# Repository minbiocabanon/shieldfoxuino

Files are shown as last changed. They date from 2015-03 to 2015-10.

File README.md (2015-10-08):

Shieldfoxuino
============

GPS tracker on an Olimexino-328 board + my Shield with TD1202 (SIGFOX) and GPS modules

More info about sigfox and Telecom Design modules : 

- http://www.sigfox.com/
- http://rfmodules.td-next.com/

How it works ?
============

SIGFOX is an IoT network provider, it allows devices to send data with long range distance. Payload message is light (12 bytes), but it is very low power and subscription is cheap.
Messages are stored in SIGFOX server that is accessible from any device connected to the Internet.

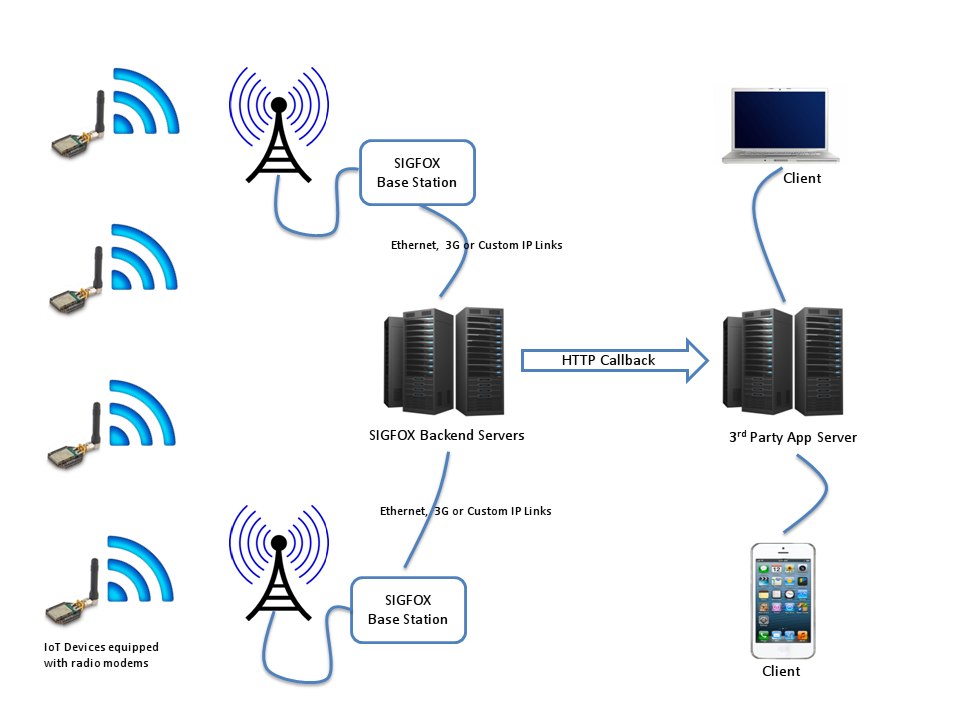
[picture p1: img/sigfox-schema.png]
sigfox archi
 
(source http://www.ekito.fr/)

The shieldfoxuino tracker is composed with a shield plugged in the olimexino-328.

 * Use Sigfow network for communication (uplink only, bidirecionnal mode is NOT supported),
 * Use GPS for geolocalisation and geofencing,
 * Monitor LiPo cell voltage and can set an alarm on low power,
 * Monitor temperature,
 * Serial messages are for debug purpose only.

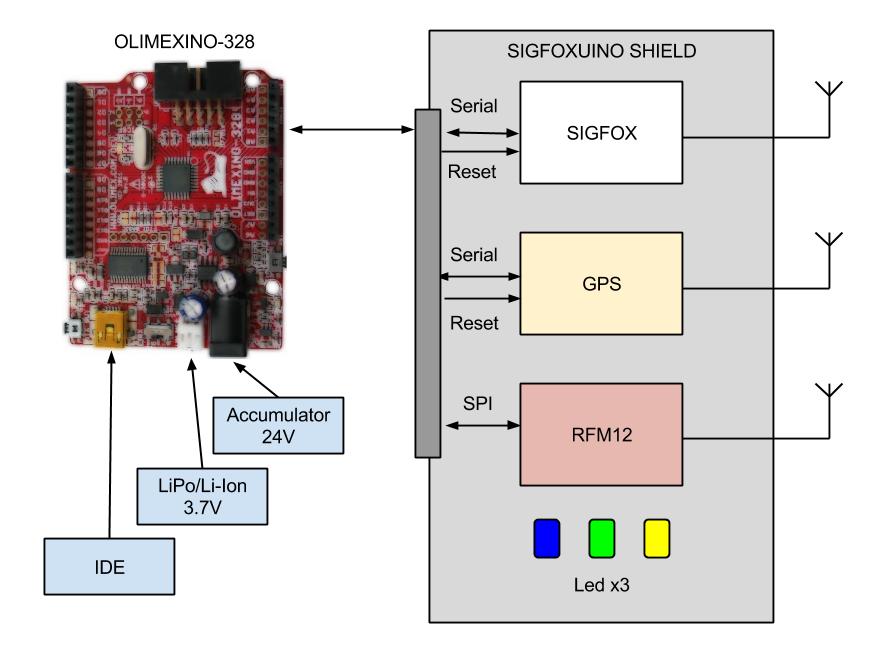
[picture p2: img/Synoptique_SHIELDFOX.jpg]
Shieldfoxuino architecture
 
 
Applications
============ 

 * My application : GPS tracker / Geofencing for my robomow (anti theft)
 * Other application without modifying source code : Geofencing, monitoring for yatch / boat parked at the harbor, ...
 * Other applications which some modification : GPS tracker for car / truck / caravan , freezer monitoring in second home when power outage, ...

Principles
============

##Geofencing

The device check if GPS position is inside an round area centered on an custom coordinates.
When device is outside this area, a message alert is through Sigfox to your server. Server application can warn you by email or SMS.

##Daily report
Each day, shieldfoxuino send a message as a keepalive message.
Message is the same as the geofencing message.

##Analog inputs

The device can monitor some analog inputs :

- LiPo battery : linkitone API only return these levels : 0 - 33 - 66 - 100% . So, by default, an SMS alert is sent to your phone when LiPo voltage is lower than 33%. This trigger is not customizable by SMS.

- Power supply voltage : device read voltage of this input and can send an SMS when is lower than a trigger. This value can be set by SMS. Default value is 11.6V (for a 12V lead battery).

## Serial port

Serial port is available on micro USB connector. It is only for debugging purpose. No maintenance or configuration messages are available through this serial port.

Screenshots
============

#Hardware setup

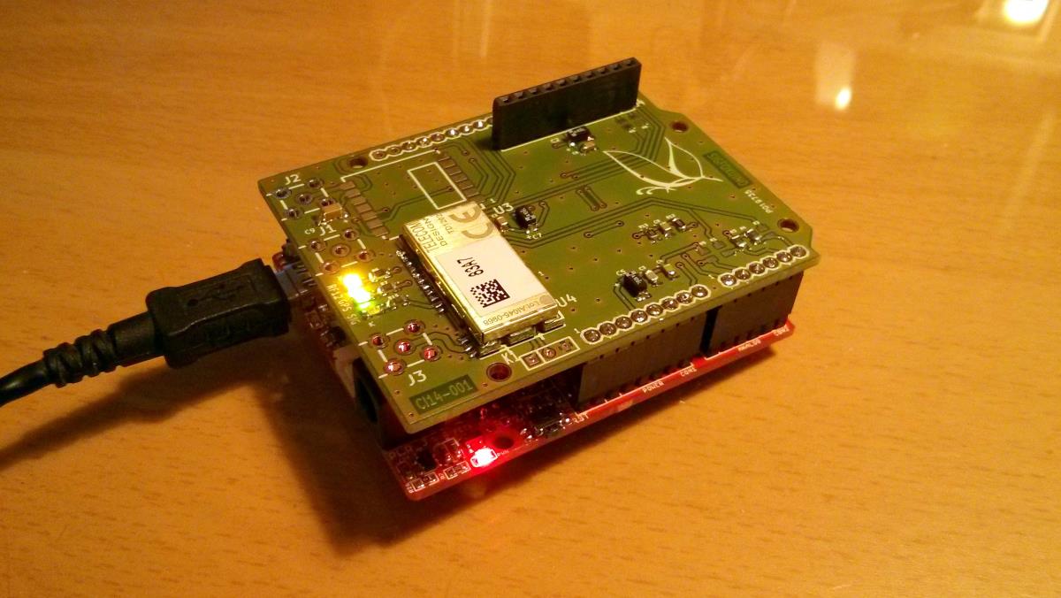
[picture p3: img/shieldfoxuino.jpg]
shieldfoxuino pic


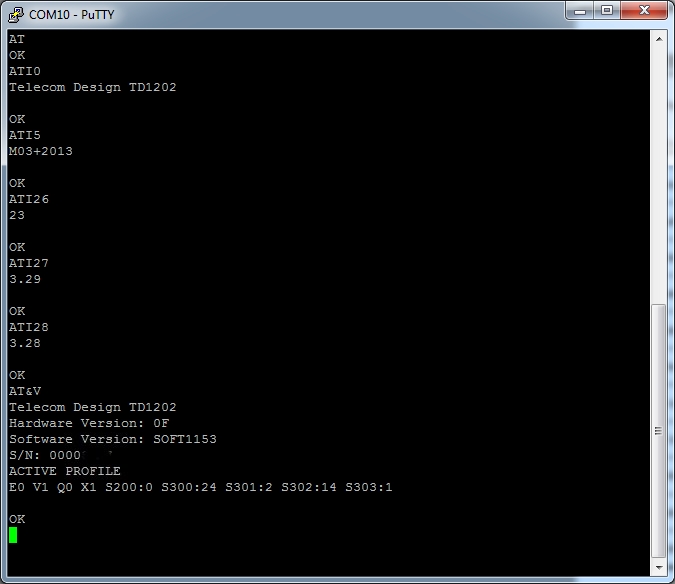
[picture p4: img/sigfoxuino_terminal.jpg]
Terminal pic


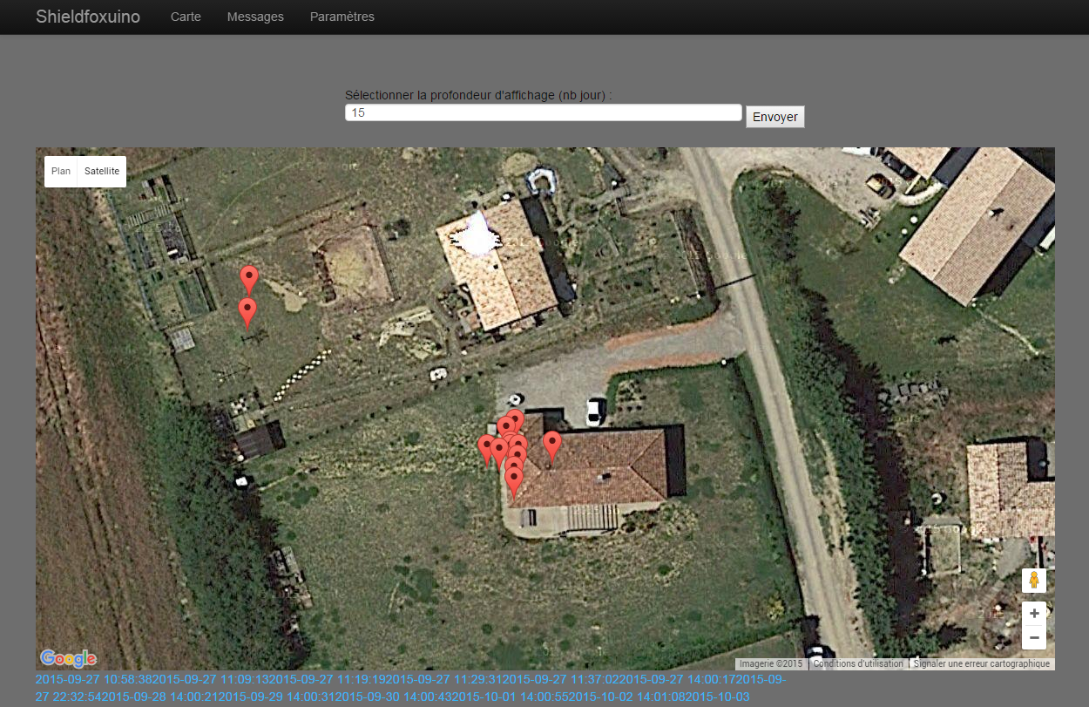
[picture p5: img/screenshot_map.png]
Map pic


Instructions
============

Don't forget to set your settings in this file :

	~\shieldfoxuino\soft\sketche_sigfoxuino\sketche_sigfoxuino.h

Compile files and uploard to olimexino-328 with arduino IDE (follow instructions in Developer's guide)

Software
============
Arduino IDE version must be 1.5.0 ! (newer version are not supported yet).

Sigfox serial interface driver is forked from this hub :
https://github.com/Ekito/hackerz_aker

API IoT 
============
Once message is send to SIGFOX network, the only way to get this message is to run a request from a machine connected to the Internet (server, computer, mobile phone ...)
You have to ask to your Sigfox provider the API side.

  * backend SIGFOX : [[https://backend.sigfox.com]]
  * backend Telecom Design : [[https://developers.insgroup.fr/]]

Hardware
============
- Olimexino-328

https://www.olimex.com/Products/Duino/AVR/OLIMEXINO-328/open-source-hardware

- plastic case

http://www.seeedstudio.com/depot/General-Plastic-Case-25x60x100-mm-p-1001.html

Troubleshooting
============

TODO

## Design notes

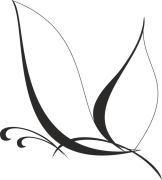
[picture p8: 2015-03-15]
img/vector_butterfly_by_jittike-d32rp64.png

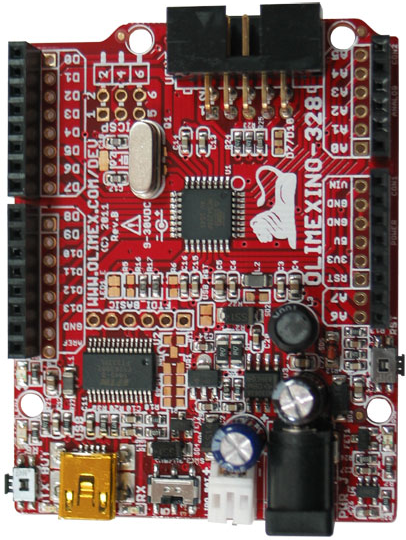
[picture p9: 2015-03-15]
Olimex/olimex328.png

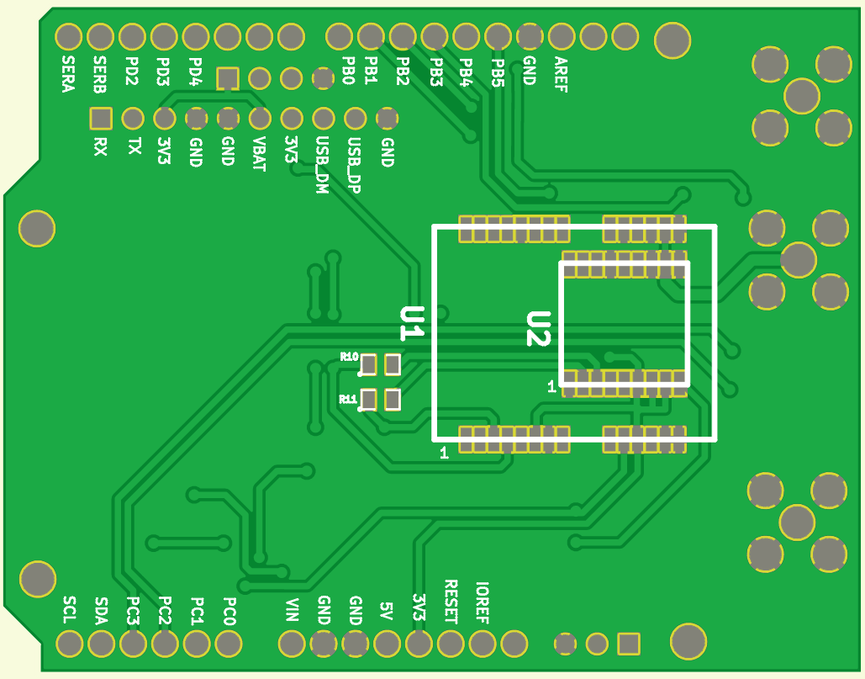
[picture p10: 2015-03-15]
schema/IMPLANTATION/CI14-001_bottom.png

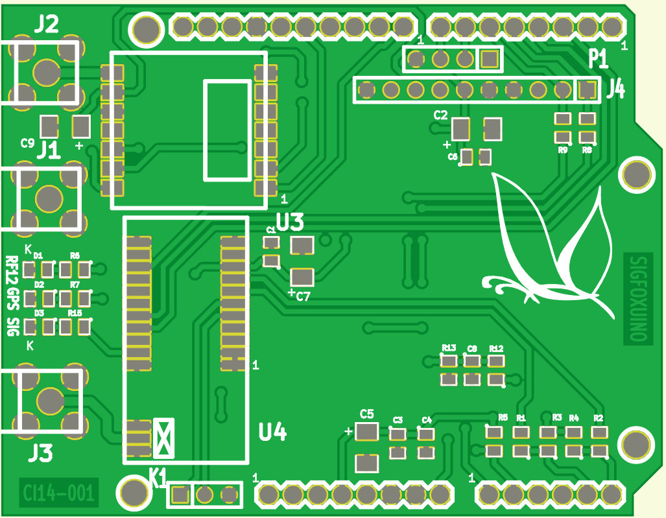
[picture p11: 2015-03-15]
schema/IMPLANTATION/CI14-001_top.png

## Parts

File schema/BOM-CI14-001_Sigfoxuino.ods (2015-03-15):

N° de circuit |  | CI14-001
 |  |  |  |  |  |  |  | Total | 21,91 €
 |  |  |  |  |  | TVA | 1,196
ref | value | footprint | Fabricant | Designation | Fournisseur | code commande |  | Prix U TTC | Prix U TTC
PCB | CI14-001 |  |  | 2 couches , 53,55 x 69,00mm | Eurocircuit | FDP compris | 3,62 € | 4,32 €
C3 | 10pF | SM0805 |  | Condensateur |  |  | 0,00 € | 0,00 €
C5 | 10uF/9V | SM1206 |  | Condensateur |  |  | 0,00 € | 0,00 €
C2 | 10uF/9V | SM1206 |  | Condensateur |  |  | 0,00 € | 0,00 €
C7 | 10uF/9V | SM1206 |  | Condensateur |  |  | 0,00 € | 0,00 €
C6 | 0.1uF | SM0805 |  | Condensateur |  |  | 0,00 € | 0,00 €
C8 | 0.1uF | SM0805 |  | Condensateur |  |  | 0,00 € | 0,00 €
C1 | 0.1uF | SM0805 |  | Condensateur |  |  | 0,00 € | 0,00 €
C4 | 0.1uF | SM0805 |  | Condensateur |  |  | 0,00 € | 0,00 €
CON6_1 | SIL06 | TSW-106-07-L-S | SAMTEC | Barette 6pts male droite | Conrad Farnell | 733993-62 1668590 | 0,15 € | 0,18 € | Gratuit en sample sur Samtec.com
CON8_2 | SIL08 | TSW-108-07-L-S | SAMTEC | Barette 8pts male droite | Conrad Farnell | 742235 – 62 - | 0,20 € | 0,24 € | Gratuit en sample sur Samtec.com
CONN10_1 | SIL10 | TSW-110-07-L-S | SAMTEC | Barette 10pts male droite | Conrad Farnell | 393481 – 62 - | 0,15 € | 0,18 € | Gratuit en sample sur Samtec.com
CONN8_1 | SIL8 | TSW-108-07-L-S | SAMTEC | Barette 8pts male droite | Conrad Farnell | 742235 – 62 - | 0,20 € | 0,24 € | Gratuit en sample sur Samtec.com
D1 | LED GREEN | SM0805 | Avago / Osram | Led CMS verte | Conrad Farnell | 153376–62 2099239 | 0,20 € | 0,24 €
D2 | LED GREEN | SM0805 | Avago / Osram | Led CMS Jaune | Conrad Farnell | 153392 – 62 - | 0,15 € | 0,18 €
D3 | LED GREEN | SM0805 | Avago / Osram | LED CMS bleu | Conrad Farnell | 759433 – 62 - | 0,30 € | 0,36 €
J1 | SMA_TH | SMA-J-P-XX-RA-TH1 | SAMTEC | Embase SMA long filetage femelle coudée 50 Ω CI | Conrad Farnell |  | 3,80 € | 4,54 € | Gratuit en sample sur Samtec.com
J2 | SMA_TH | SMA-J-P-XX-RA-TH1 | BKL | Embase SMA long filetage femelle coudée 50 Ω CI | Conrad Farnell |  | 3,80 € | 4,54 € | Gratuit en sample sur Samtec.com
J3 | SMA_TH | SMA-J-P-XX-RA-TH1 | BKL | Embase SMA long filetage femelle coudée 50 Ω CI | Conrad Farnell |  | 3,80 € | 4,54 € | Gratuit en sample sur Samtec.com
J4 | SIL10 | SSW-110-01-F-S | SAMTEC | Barette 10pts Femelle droite | Conrad Farnell | 741129 – 62 - | 0,65 € | 0,78 € | Gratuit en sample sur Samtec.com
K1 | SIL10 | SSW-110-01-F-S | SAMTEC | Barette 10pts Femelle droite | Conrad Farnell | 741129 – 62 - | 0,65 € | 0,78 € | Gratuit en sample sur Samtec.com
P1 | SIL10 | SSW-110-01-F-S | SAMTEC | Barette 10pts Femelle droite | Conrad Farnell | 741129 – 62 - | 0,65 € | 0,78 € | Gratuit en sample sur Samtec.com
R1 | 0R0 | SM0805 |  | Résistance 10 % |  |  | 0,00 € | 0,00 €
R2 | 0R0 | SM0805 |  | Résistance 10 % |  |  | 0,00 € | 0,00 €
R3 | 4K7 | SM0805 |  | Résistance 10 % |  |  | 0,00 € | 0,00 €
R4 | 4K7 | SM0805 |  | Résistance 10 % |  |  | 0,00 € | 0,00 €
R5 | 47K | SM0805 |  | Résistance 10 % |  |  | 0,00 € | 0,00 €
R6 | 220R | SM0805 |  | Résistance 10 % |  |  | 0,00 € | 0,00 €
R7 | 220R | SM0805 |  | Résistance 10 % |  |  | 0,00 € | 0,00 €
R8 | 0R | SM0805 |  | Résistance 10 % |  |  | 0,00 € | 0,00 €
R9 | 0R | SM0805 |  | Résistance 10 % |  |  | 0,00 € | 0,00 €
R10 | 0R | SM0805 |  | Résistance 10 % |  |  | 0,00 € | 0,00 €
R11 | 0R | SM0805 |  | Résistance 10 % |  |  | 0,00 € | 0,00 €
R12 | 10K | SM0805 |  | Résistance 10 % |  |  | 0,00 € | 0,00 €
R13 | 1K | SM0805 |  | Résistance 10 % |  |  | 0,00 € | 0,00 €
R15 | 220R | SM0805 |  | Résistance 10 % |  |  | 0,00 € | 0,00 €
U1 | LEA-7X | LEA-xx | uBlox | Récepteur GPS |  |  | 0,00 € | 0,00 €
U2 | MAX-7X | MAX-xx | uBlox | Récepteur GPS |  |  | 0,00 € | 0,00 €
U3 | RFM12 | RFM12 | HopeRF | E/R radio 869MHz/433Mhz |  |  | 0,00 € | 0,00 €
U4 | TD1202 | TD1202 | Telecom Design | E/R radio 869MHz longue portée |  |  | 0,00 € | 0,00 €
ACCESSOIRES
ref | value | footprint | Fabricant | Designation | Fournisseur | code commande |  | Prix U TTC
 | OLIMEXINO-328 |  | OLIMEX | Cartes compatible arduino UNO | LEXTRONIC | OLIMEX328 | 24,75 € | 29,60 €
 | LEA Smart antenna |  | Ublox | Kit récepteur GPS + antenne céramique

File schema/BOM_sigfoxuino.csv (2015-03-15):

ref | value | footprint
C1 | 0.1uF | SM0805
C2 | 10uF/9V | SM1206
C3 | 10pF | SM0805
C4 | 0.1uF | SM0805
C5 | 10uF/9V | SM1206
C6 | 0.1uF | SM0805
C7 | 10uF/9V | SM1206
C8 | 0.1uF | SM0805
C9 | 1uF/9V | SM1206
CON6_1 | CONN_6 | SIL-6
CON8_2 | CONN_8 | SIL-8
CONN10_1 | CONN_10 | SIL-10
CONN8_1 | CONN_8 | SIL-8
D1 | LED GREEN | SM0805
D2 | LED GREEN | SM0805
D3 | LED GREEN | SM0805
J1 | SMA_TH | SMA-SMB_right_angle
J2 | SMA_TH | SMA-SMB_right_angle
J3 | SMA_TH | SMA-SMB_right_angle
J4 | SIL10 | SIL-10
K1 | CONN_3 | SIL-3
P1 | CONN_4 | ~
R1 | 0R0 | SM0805
R2 | 0R0 | SM0805
R3 | 4K7 | SM0805
R4 | 4K7 | SM0805
R5 | 47K | SM0805
R6 | 220R | SM0805
R7 | 220R | SM0805
R8 | 0R | SM0805
R9 | 0R | SM0805
R10 | 0R | SM0805
R11 | 0R | SM0805
R12 | 10K | SM0805
R13 | 1K | SM0805
R15 | 220R | SM0805
U1 | LEA-7X | LEA-xx
U2 | MAX-7X | MAX-xx
U3 | RFM12 | RFM12
U4 | TD1202 | TD1202

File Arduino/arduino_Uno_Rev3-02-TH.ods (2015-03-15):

Arduino Uno R3 Through-Hole |  |  |  | Rugged Circuits LLC http://ruggedcircuits.com Look for the latest version at http://ruggedcircuits.com/html/application_notes.html This bill-of-materials is a best-effort estimate and comes with no warranty. Please direct all corrections to <support@ruggedcircuits.com>
 | Qty | Part Number | Manufacturer | Package | Reference | Description | Digi-Key P/N | Mouser P/N | Newark P/N
Capacitors
 | 2 | 500R14N220JV4T | Johanson | 0603 | C9, C11 | 22pF capacitor ceramic | 709-1143-1-ND
 | 2 | MC0603N220J500CT | Multicomp | 0603 | C9, C11 | 22pF capacitor ceramic |  |  | 06R5149
 | 2 | VJ0603A220KXQPW1BC | Vishay | 0603 | C9, C11 | 22pF capacitor ceramic |  | 77-VJ0603A220KXQPBC
 | 6 | CC0603KRX7R9BB104 | Yageo | 0603 | C1, C2, C4, C5, C6, C7 | 100nF capacitor ceramic | 311-1344-1-ND
 | 6 | C0603C104K5RACTU | Kemet | 0603 | C1, C2, C4, C5, C6, C7 | 100nF capacitor ceramic |  |  | 72J5992
 | 6 | GRM188R71H104KA93D | Murata | 0603 | C1, C2, C4, C5, C6, C7 | 100nF capacitor ceramic | 490-1519-1-ND | 81-GRM39X104K50D | 38K1670
 | 2 | GRM188R60J105KA01D | Murata | 0603 | C3, C8 | 1uF capacitor ceramic 6.3V | 490-1550-1-ND | 81-GRM39R105K6.3
 | 2 | C1608X5R1A105MT | TDK | 0603 | C3, C8 | 1uF capacitor ceramic 10V |  | 810-C1608X5R1A105M
 | 2 | EMVA250ADA470MF55G | UCC | SMD | PC1, PC2 | 47uF electrolytic capacitor SMT | 565-2103-1-ND | 661-EMVA250ADA470MF5 | 76K1185
 | 2 | AVE476M50X16T-F | Cornell | SMD | PC1, PC2 | 47uF electrolytic capacitor SMT |  | 598-AVE476M50X16T-F
Connectors
 | 1 | PJ-102A | CUI | PTH | X1 | 2.1mm DC power jack | CP-102A-ND
 | 1 | USB-B1HSW6 | On Shore | PTH | X2 | USB type B connector right-angle – white | ED2982-ND
 | 1 | USB-B1HSB6 | On Shore | PTH | X2 | USB type B connector right-angle – black | ED2983-ND
 | 1 | 67996-404HLF | FCI | PTH | JP2 | Pin header 0.1” 2x2 | 609-3390-ND | 649-67996-404HLF
 | 2 | 67996-406HLF | FCI | PTH | ICSP, ICSP1 | Pin header 0.1” 2x3 | 609-3218-ND | 649-67996-406HLF | 20M2191
 | 1 | M20-7820646 | Harwin | PTH | AD | Socket strip 0.1” 1x6 |  | 855-M20-7820646
 | 1 | 5-534237-4 | TE | PTH | AD | Socket strip 0.1” 1x6 | A32907-ND |  | 62M8851
 | 2 | 960108-6202-AR | 3M | PTH | IOL, POWER | Socket strip 0.1” 1x8 | 3M9518-ND | 517-9601086202AR | 62R6734
 | 2 | M20-7820842 | Harwin | PTH | IOL, POWER | Socket strip 0.1” 1x8 |  | 855-M20-7820842
 | 1 | M20-7821046 | Harwin | PTH | IOH | Socket strip 0.1” 1x10 |  | 855-M20-7821046
 | 1 | 5-534237-8 | TE | PTH | IOH | Socket strip 0.1” 1x10 | A32910-ND | 571-5-534237-8 | 52K3746
Crystals
 | 1 | ATS16B | CTS | HC49/US | Y1 | 16MHz 18pF | CTX1085-ND | 774-ATS16B
 | 1 | ABL-16.000MHZ-B2 | Abracon | HC49/US | Y1 | 16MHz 18pF |  | 815-ABL-16-B2 | 13J1628
Diodes
 | 2 | CD1206-S01575 | Bourns | 1206 | D2, D3 | Switching diode |  | 652-CD1206-S01575 | 09J8040
 | 1 | S2M-13-F | Diodes Inc | SMB | D1 | Switching diode | S2M-FDICT-ND | 621-S2M-F
 | 1 | S2J | Fairchild | SMB | D1 | Switching diode | S2J-TPMSCT-ND | 512-S2J | 05R5915
Ferrites
 | 1 | BLM21PG221SN1D | Murata | 0805 | L1 | Ferrite 50mOhm@DC / 220ohm@100MHz | 490-1054-1-ND | 81-BLM21P221SG
Fuses
 | 1 | MF-MSMF050-2 | Bourns | 1812 | F1 | Fuse 500mA 15V | MF-MSMF050-2CT-ND | 652-MF-MSMF050-2 | 02J2718
IC's
 | 1 | ATMEGA16U2-MUR | Atmel | VQFN-32 | U3 | ATmega16U2 16kB FLASH | ATMEGA16U2-MURCT-ND | 556-ATMEGA16U2-MUR
 | 1 | ATMEGA328P-PU | Atmel | DIP-28 | ZU4 | ATmega328P | ATMEGA328P-PU-ND | 556-ATMEGA328P-PU | 15R0268
 | 1 | LMV358IDGKR | TI | MSOP-8 | U5 | Dual op-amp RRO | 296-13455-1-ND | 595-LMV358IDGKR
 | 1 | MCP6002-E/MS | Microchip | MSOP-8 | U5 | Dual op-amp RRO | MCP6002-E/MS-ND | 579-MCP6002-E/MS | 88H9854
 | 1 | LP2985-33DBVR | TI | SOT-23-5 | U2 | 150mA 3.3V LDO | 296-18476-1-ND | 595-LP2985-33DBVR | 43J9346
 | 1 | NCP1117ST50T3G | ON Semi | SOT-223 | U1 | 1A 5V LDO | NCP1117ST50T3GOSCT-ND | 863-NCP1117ST50T3G | 71J6563
LED's
 | 1 | LG R971-KN-1-0-20-R18 | Osram | 0805 | ON | LED green | 475-1410-1-ND
 | 1 | 598-8160-107F | Dialight | 0805 | ON | LED green | 350-2043-1-ND | 645-598-8160-107F | 75R0586
 | 3 | LTST-C171KSKT | Lite-On | 0805 | L, RX, TX | LED yellow | 160-1428-1-ND | 859-LTST-C171KSKT
 | 3 | APT2012YC | Kingbright | 0805 | L, RX, TX | LED yellow | 754-1135-1-ND | 604-APT2012YC
Resistors
 | 1 | CAY16-220J4LF | Bourns | 1206 | RN3 | 22ohm 4-resistor series array | CAY16-220J4LF-ND | 652-CAY16-220J4LF
 | 2 | CAY16-102J4LF | Bourns | 1206 | RN2, RN4 | 1k 4-resistor series array | CAY16-102J4LF-ND | 652-CAY16-102J4LF | 96M0890
 | 1 | CAY16-103J4LF | Bourns | 1206 | RN1 | 10k 4-resistor series array | CAY16-103J4LF-ND | 652-CAY16-103J4LF | 02J1097
 | 2 | ERJ-3GEYJ105V | Panasonic | 0603 | R1, R2 | 1M resistor 5% 1/10W | P1.0MGCT-ND | 667-ERJ-3GEYJ105V
 | 2 | CR0603-JW-105GLF | Bourns | 0603 | R1, R2 | 1M resistor 5% 1/10W |  | 652-CR0603-JW-105GLF | 32K2615
Resonators
 | 1 | CSTCE16M0V53-R0 | Murata | SMD | Y2 | 16MHz resonator with built-in caps | 490-1198-1-ND | 81-CSTCE16M0V53-R0
Switches
 | 1 | TS42031-160R-TR-7260 | ??? | SMT | RESET | Tactile switch
Transistors
 | 1 | FDN340P | Fairchild | SOT-23 | T1 | 20V P-type MOSFET | FDN340PCT-ND | 512-FDN340P | 58K8841
Varistors
 | 2 | CG0603MLC-05E | Bourns | 0603 | Z1, Z2 | Low-capacitance varistor 5V WV | CG0603MLC-05E-ND | 652-CG0603MLC-05E | 97M3815

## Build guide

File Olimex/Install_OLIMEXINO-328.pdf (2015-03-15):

## Install OLIMEXINO-328

by LadyMM

The olimexino-328 is an arduino-like borad, which runs programs called “sketches”. The programs themselves are written in C/C++ and compiled in the Arduino environment and then uploaded to the board’s memory via miniUSB.

Special drivers and settings are needed, however, for your computer to correctly recognise the board. Installation instructions are below.

1.Installation of the arduino-based board
(Instrusctions and screenshots from Limor Fried http://www.ladyada.net/learn/arduino)

Visit http://www.ftdichip.com/Drivers/VCP.htm for the latest drivers for your Olimexino-328 board
(Instructions for other arduino boards can be found at http://arduino.cc/en/Guide/HomePage )

Windows:
(The screenshots show a Windows XP machine, but the installation is the same for XP/Vista/Windows7)

When you plug in the Arduino, you may hear a sound from the computer and a little popup bubble in the bottom right corner of the screen that says Found New Hardware FT232R USB UART

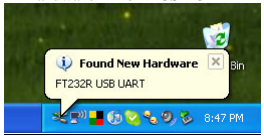
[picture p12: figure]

After a few seconds, the new hardware wizard will start. Select "No not this time" and click Next>

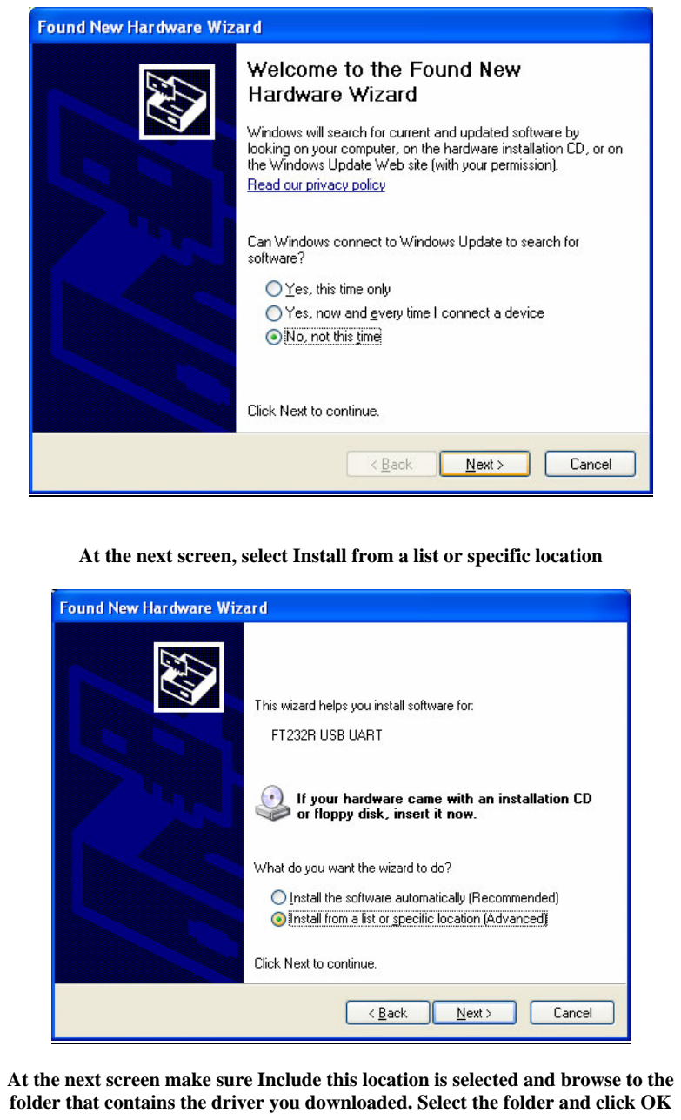
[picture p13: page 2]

At the next screen, select Install from a list or specific location

At the next screen make sure Include this location is selected and browse to the folder that contains the driver you downloaded. Select the folder and click OK

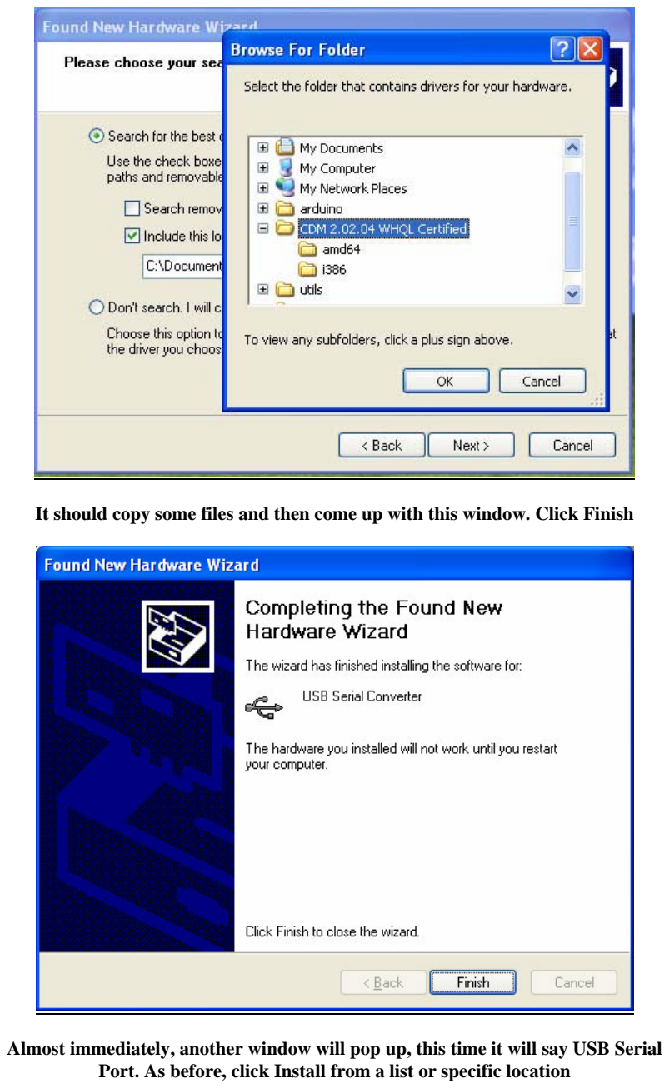
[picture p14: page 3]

It should copy some files and then come up with this window. Click Finish

Almost immediately, another window will pop up, this time it will say USB Serial Port. As before, click Install from a list or specific location

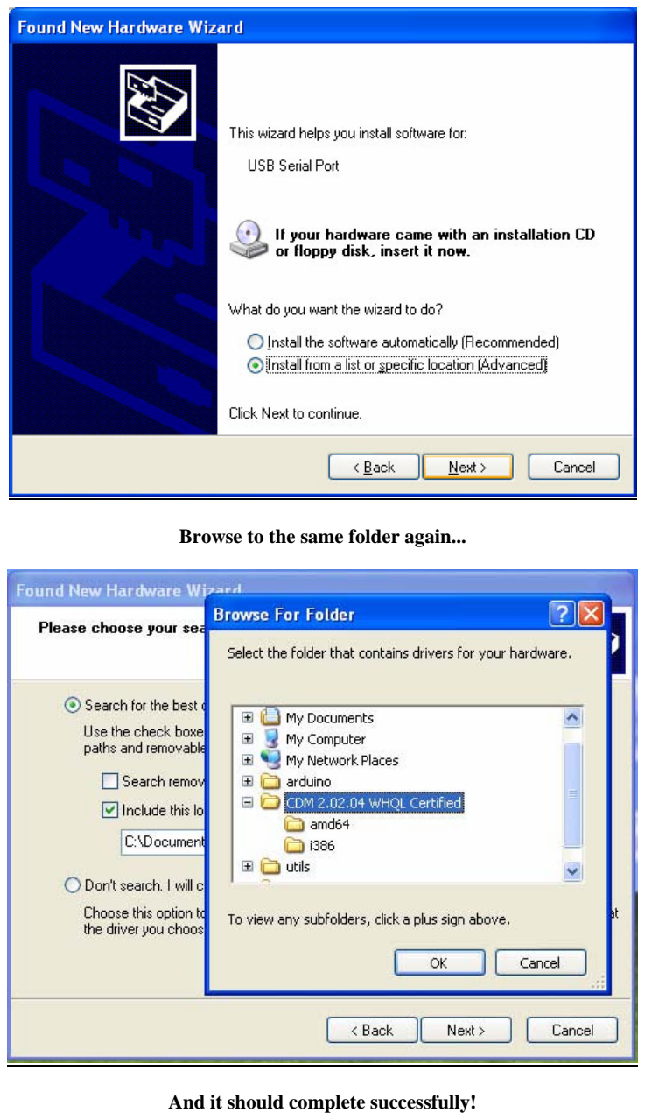
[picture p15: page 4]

Browse to the same folder again...

And it should complete successfully!

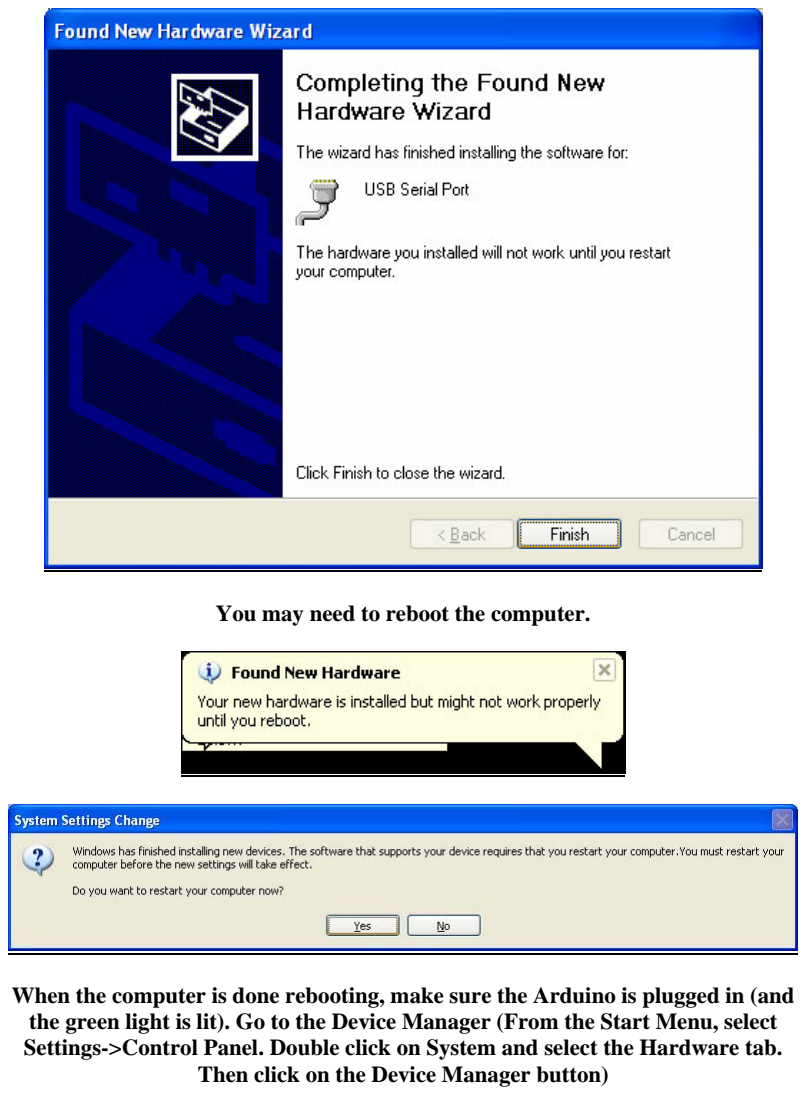
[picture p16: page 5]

You may need to reboot the computer.

When the computer is done rebooting, make sure the Arduino is plugged in (and the green light is lit). Go to the Device Manager (From the Start Menu, select Settings->Control Panel. Double click on System and select the Hardware tab. Then click on the Device Manager button)

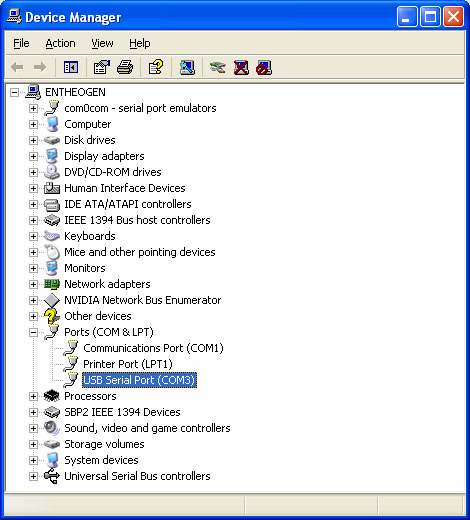
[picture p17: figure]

Look for an entry under Ports (COM & LPT) that says USB Serial Port (COM) the COM number may vary but it should be something like COM3 or COM4. The COM stands for "communication", and each one has a unique number, known as the COM Port number. In this case the COM Port number is COM3.

If you don't see the COM port verify the Arduino is plugged in, and check that you installed the VCP FTDI driver.

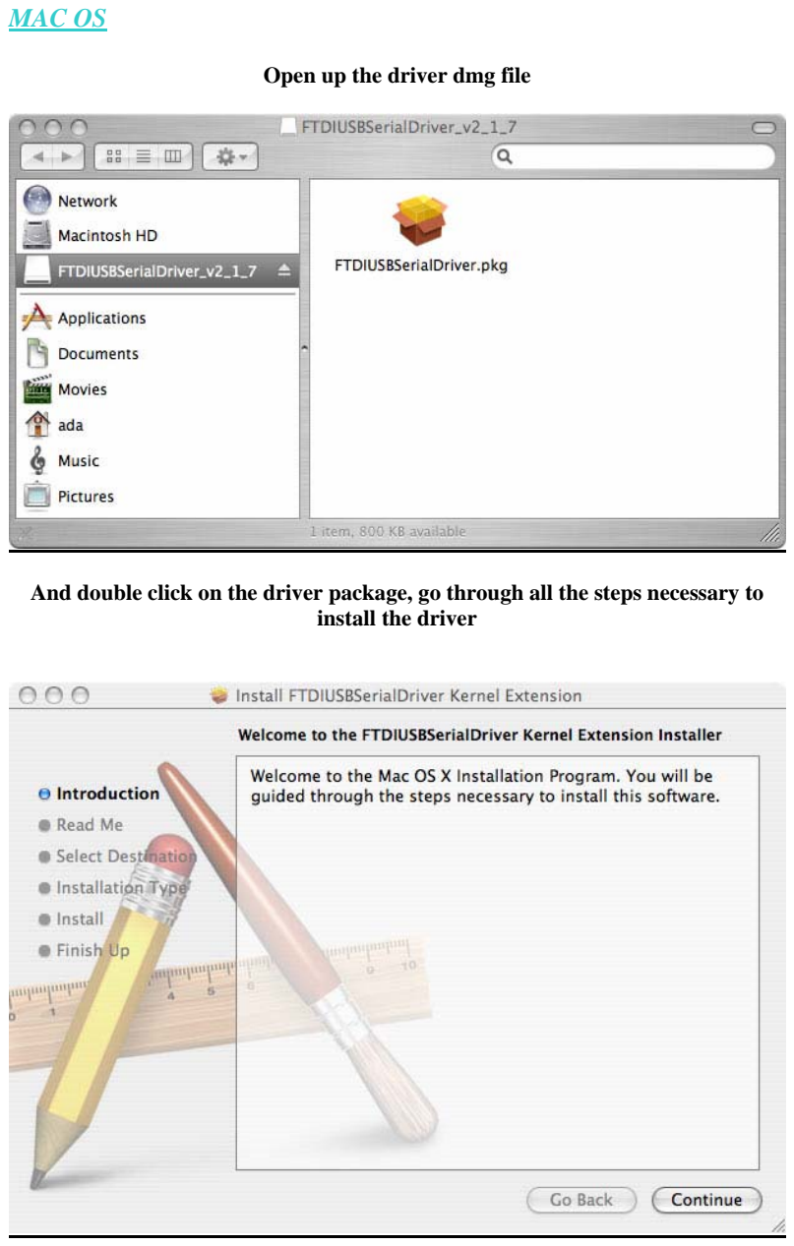
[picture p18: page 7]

MAC OS

Open up the driver dmg file

And double click on the driver package, go through all the steps necessary to install the driver

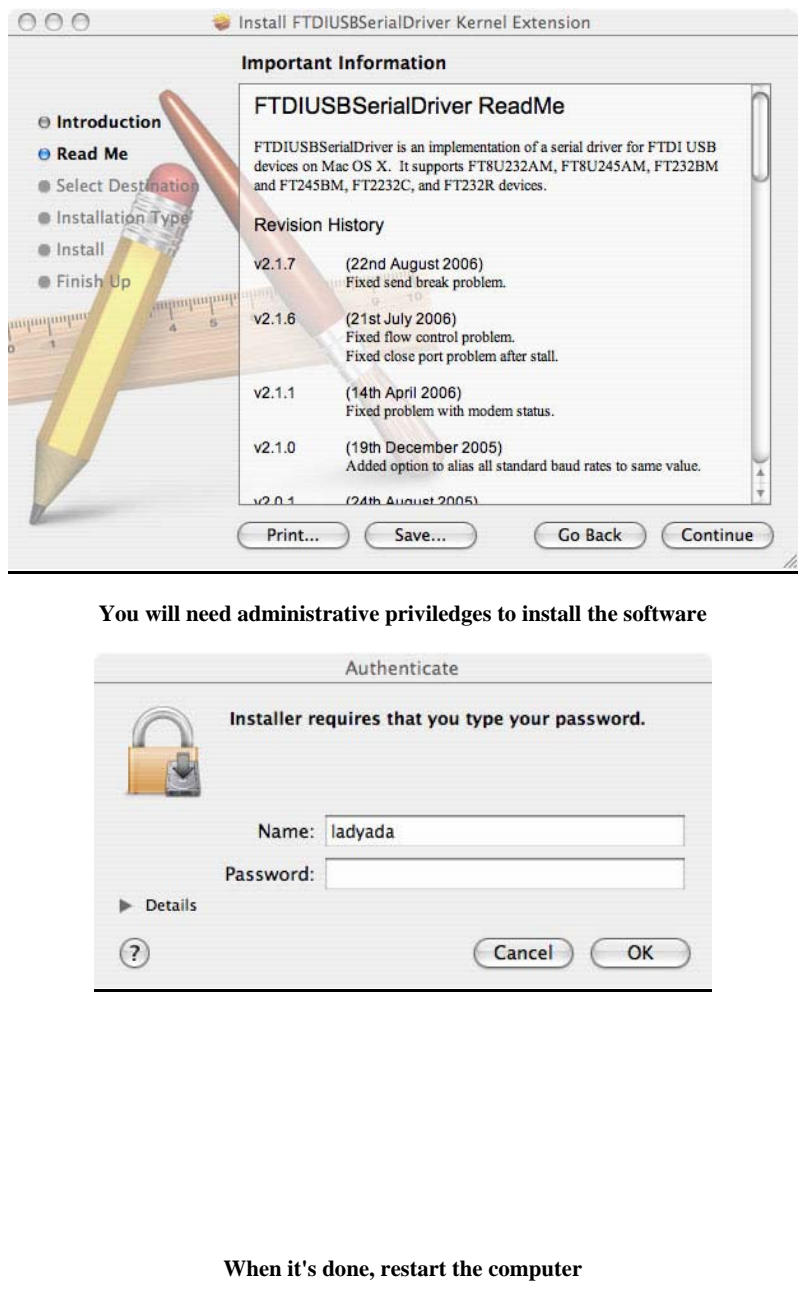
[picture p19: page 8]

You will need administrative priviledges to install the software

When it's done, restart the computer

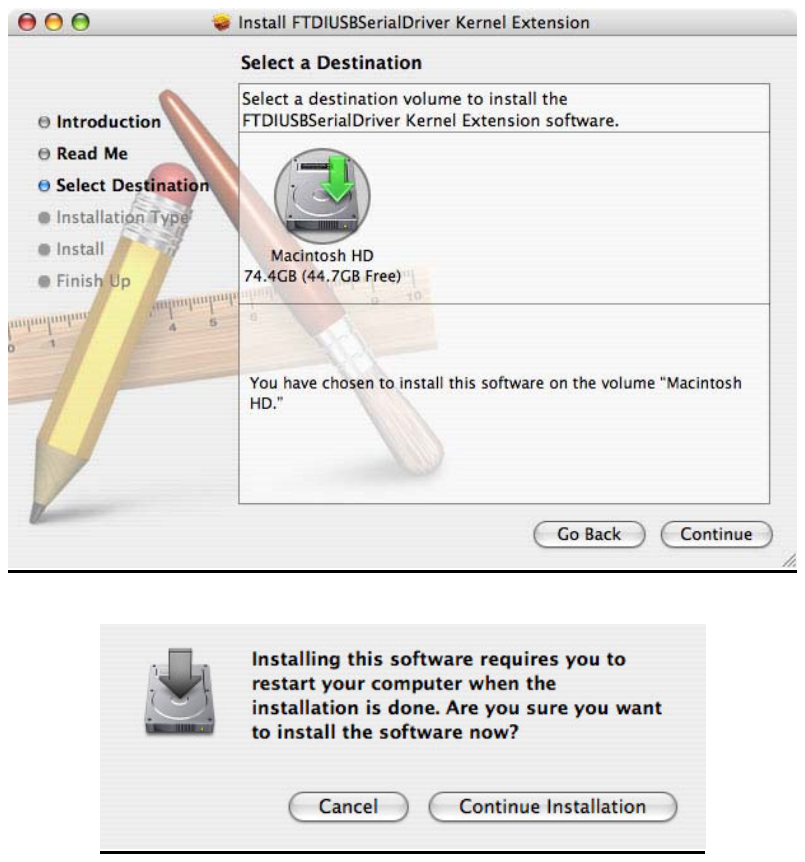
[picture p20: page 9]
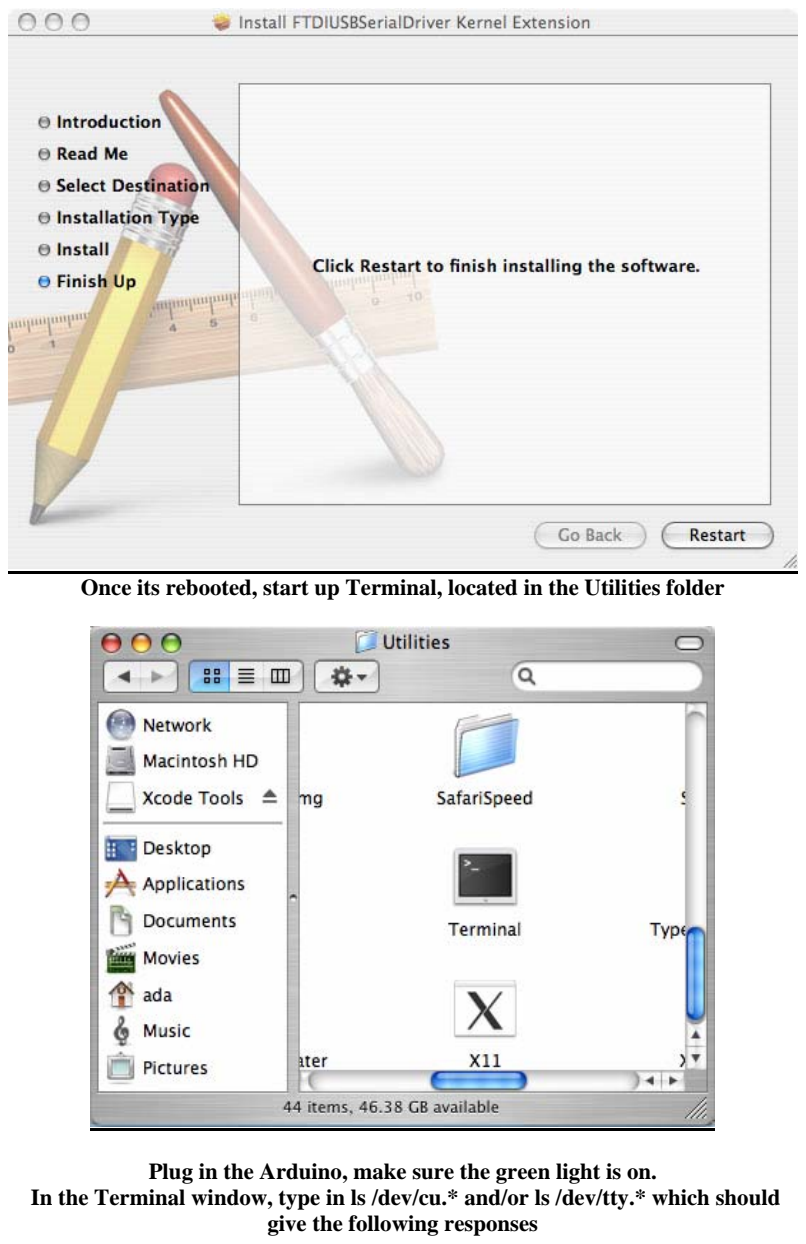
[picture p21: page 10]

Once its rebooted, start up Terminal, located in the Utilities folder

Plug in the Arduino, make sure the green light is on. In the Terminal window, type in ls /dev/cu.* and/or ls /dev/tty.* which should give the following responses

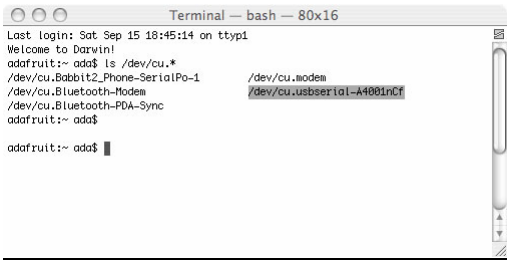
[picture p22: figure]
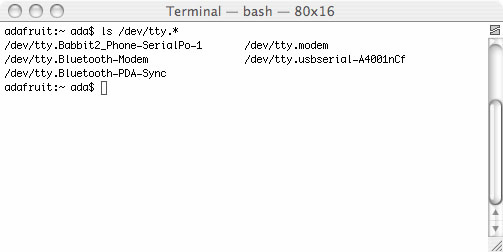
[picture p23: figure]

Make sure you see a line with the text /dev/cu.usbserial-xxxxx where the xxx's can be anything. Same for /dev/tty.usbserial-xxxxx. This indicates that the driver installed properly and that the Arduino was found.

If you can't find the text, verify that your Arduino is plugged in, try a different USB port.
You can also try running the Console application, which will possibly give you some information about why its failing.

### LINUX

Linux doesn't have any drivers to install, assuming you're running a v2.6 kernel. These instructions assume you're running Ubuntu. Each linux distribution is different, but the instructions should be basic enough to follow for other distros.

You can verify your kernel version by running uname -a in a terminal window, note that this kernel is version 2.6.20

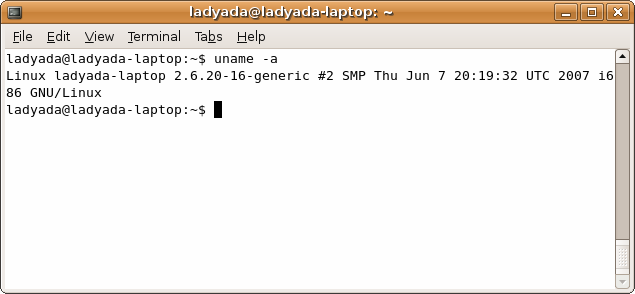
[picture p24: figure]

Sometimes the Linux distribution installs brltty (braille device) which will conflict with the Arduino. You must uninstall brltty! Do so by running

sudo apt-get remove brltty

In a terminal window. If it says it's not installed then thats OK. If you're not running a Debian-derived installation use whatever tool is necessary to verify that you don't have brltty running

Plug in the Arduino, verify that the green LED is lit, and type ls /dev/ttyUSB* into a terminal window, you should see a device file called something like ttyUSB0

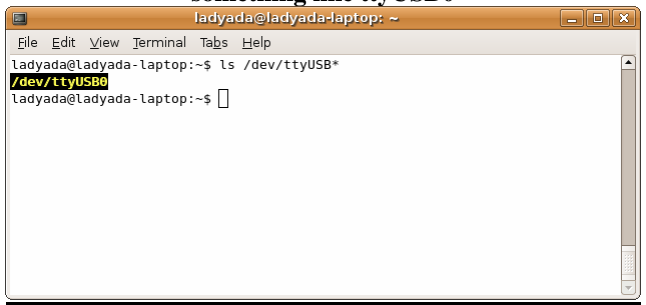
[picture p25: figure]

Depending on your Linux distro, it may be /dev/tty/USB0 or /dev/tty.USB etc.

If you can't seem to find it, use dmesg | tail right after plugging in the
Arduino and look for hints on where it may put the device file. For example here is says Serial Device converter now attached to ttyUSB0

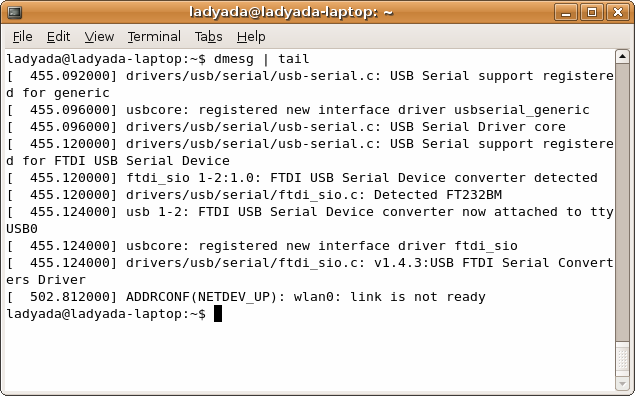
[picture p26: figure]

If you see something like this [ 1900.712000] ftdi_sio 2-10:1.0: FTDI USB Serial Device converter detected
[ 1900.712000] drivers/usb/serial/ftdi_sio.c: Detected FT232BM
[ 1900.712000] usb 2-10: FTDI USB Serial Device converter now attached to ttyUSB0
[ 1901.868000] usb 2-10: usbfs: interface 0 claimed by ftdi_sio while 'brltty' sets config #1
[ 1901.872000] ftdi_sio ttyUSB0: FTDI USB Serial Device converter now disconnected from ttyUSB0
[ 1901.872000] ftdi_sio 2-10:1.0: device disconnected

That means you have not uninstalled brltty and you should try again.

### 2.Configuring The Arduino Environment

### 1. Getting the arduino environment:

Download the latest arduino for your OS from: http://arduino.cc/en/Main/Software

The arduino environment is portable and only needs to be extracted from the archive.

2.Configuring the arduino environment

- Remember the COM port that your board received during installation – then choose the same number from Tools/Serial Port/COMX where X is the number of the correct port.
- Since you are using the Olimexino-328, go to Tools/Board and choose the option shown below on the screenshot.

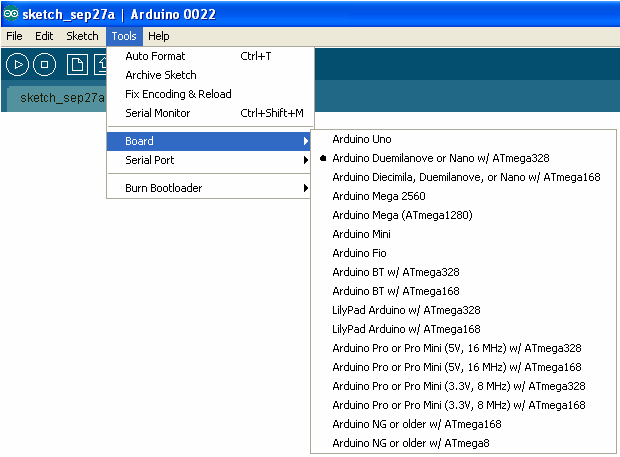
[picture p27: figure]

Now your board should be configured and you can try running some of the example sketches, or start making your own.

Some useful links for those, who are new to the C/C++ language and/or the Arduino environment:

http://arduino.cc/en/Tutorial/HomePagehttp://arduino.cc/en/Reference/HomePagehttp://www.acm.uiuc.edu/webmonkeys/book/c_guide/http://en.wikipedia.org/wiki/C_(programm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 http://arduino.cc/en/Guide

http://www.olimex.com/

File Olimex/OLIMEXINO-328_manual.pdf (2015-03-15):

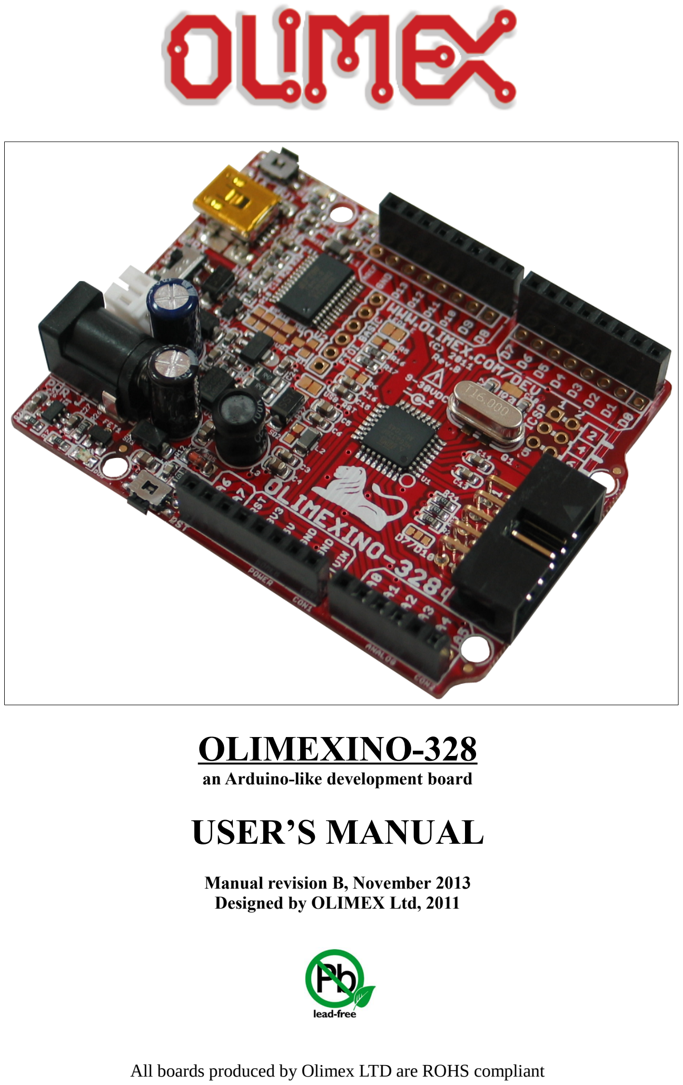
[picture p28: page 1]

# OLIMEXINO-328

an Arduino-like development board

# USER’S MANUAL

Manual revision B, November 2013 Designed by OLIMEX Ltd, 2011

All boards produced by Olimex LTD are ROHS compliant

OLIMEX© 2013 | OLIMEXINO-328 user's manual

### DISCLAIMER

© 2013 Olimex Ltd. Olimex®, logo and combinations thereof, are registered trademarks of Olimex Ltd. Other product names may be trademarks of others and the rights belong to their respective owners.

The information in this document is provided in connection with Olimex products. No license, express or implied or otherwise, to any intellectual property right is granted by this document or in connection with the sale of Olimex products.

This work is licensed under the Creative Commons Attribution-ShareAlike 3.0 Unported License. To view a copy of this license, visit http://www.creativecommons.org/licenses/by-sa/3.0/.

This hardware design by Olimex LTD is licensed under a Creative Commons Attribution-ShareAlike 3.0 Unported License.

The software is released under GPL.

It is possible that the pictures in this manual differ from the latest revision of the board.

The product described in this document is subject to continuous development and improvements. All particulars of the product and its use contained in this document are given by OLIMEX in good faith. However all warranties implied or expressed including but not limited to implied warranties of merchantability or fitness for purpose are excluded. This document is intended only to assist the reader in the use of the product. OLIMEX Ltd. shall not be liable for any loss or damage arising from the use of any information in this document or any error or omission in such information or any incorrect use of the product.

This evaluation board/kit is intended for use for engineering development, demonstration, or evaluation purposes only and is not considered by OLIMEX to be a finished end-product fit for general consumer use. Persons handling the product must have electronics training and observe good engineering practice standards. As such, the goods being provided are not intended to be complete in terms of required design-, marketing-, and/or manufacturing-related protective considerations, including product safety and environmental measures typically found in end products that incorporate such semiconductor components or circuit boards.

Olimex currently deals with a variety of customers for products, and therefore our arrangement with the user is not exclusive. Olimex assumes no liability for applications assistance, customer product design, software performance, or infringement of patents or services described herein.

THERE IS NO WARRANTY FOR THE DESIGN MATERIALS AND THE COMPONENTS USED TO CREATE OLIMEXINO-328. THEY ARE CONSIDERED SUITABLE ONLY FOR OLIMEXINO-328.

## Table of Contents

### CHAPTER 1 - OVERVIEW

### 1. Introduction to the chapter

Thank you for choosing the OLIMEXINO-328 board from Olimex! This document provides a user’s guide for the Olimex Arudino-like OLIMEXINO-328. As an overview, this chapter gives the introduction to Arduino, the scope of this document and lists the features of the board. The document’s organization is then detailed.

### 1.1 Introduction to Arduino

Arduino is an open-source electronics prototyping platform, designed to make the process of using electronics in multidisciplinary projects more accessible. The hardware consists of a simple open design for the Arduino board with an Atmel AVR processor and on-board I/O support. The software consists of a standard programming language and the boot loader that runs on the board.
Arduino hardware is programmed using a Wiring-based language (syntax + libraries), similar to C+ + with some simplifications and modifications, and a processing-based IDE.

The project began in Ivrea, Italy in 2005 to make a device for controlling student-built interaction design projects less expensively than other prototyping systems available at the time. As of February 2010 more than 120,000 Arduino boards had been shipped. Founders Massimo Banzi and David Cuartielles named the project after Arduino, a local bar. The name is an Italian masculine first name, meaning "strong friend". The English pronunciation is "Hardwin", a namesake of Arduino of Ivrea.

More information can be found at the creators web page http://arduino.cc/ and in the Arduino Wiki http://en.wikipedia.org/wiki/Arduino. To make the story short - Arduino is easy for the beginners with minimal Electronics knowledge, while not restricting the professionals, as they can program it in C++ or a mix of Arduino/C++ language.

There are thousands of projects which make the startup easy as there is almost no
field Arduino enthusiasts have not explored already.

### 1.2 Improvements over the original Arduino design

We entered the Arduino field 5 years after the design was introduced, allowing us to see and skip most of the errors the Arduino inventors made. We were able to read feedback from current customers and to implement what they wanted to see in the original Arduino.

There are a number of improvements over the original Arduino design that we have implemented in OLIMEXINO-328:

1. We allowed the board to work at different frequencies with easy exchange of the quartz crystal.
2. The original Arduino used a linear power supply. This limited the input voltage range. We designed a switching power supply to accept input voltages from 9 to 30V DC, making it possible to use virtually any power supply adapter on the market, including applications with the standard 24VDC industrial power supply.
3. We carefully selected all components to work reliably over the industrial temperature range -25+85C so the board can be used in industrial applications (the original design was suitable for the commercial 0-70C operating temperature).
4. The original Arduino design was not good for portable applications as it dissipated too much power in the linear voltage regulators. We chose ULTRA LOW POWER voltage regulators with consumption of only few microamps to enable handheld and battery powered applications.
5. We added a Li-Ion rechargeable battery power supply option with a BUILT-IN onboard charger, so when a battery is attached it is automatically kept charged . When the other power source (USB or external adapter) is removed it will AUTOMATICALLY power the board - no jumpers, no switches!
6. Our design can work both on 3.3V and on 5V, switch-selectable.
7. Our boards included the UEXT connector, allowing many existing modules like RF, ZIGBEE, GSM, and GPS to be connected. It also saves soldering to interface I2C, UART and/or SPI.
8. Our design allows a Real Time Clock (RTC).
9. We made our design noise immune in the RESET circuit. There are a number of threads on the Arduino forum for problems with the RESET when the board works with motors, since Atmel recommendations were omitted in the original design. We fixed this.
10. We used a separate voltage regulator for the Analog part, allowing the ADC to be read correctly without digital noise pickup.
11. We made provision for the optional ARef precision voltage source, for users who need higher precision and temperature stability in Analog readings.
12. We placed the LEDs and the BUTTONs on the edge of the board for easy access even if the boards have shields on them.
13. All components were placed LOWER than the connectors, so the shields do not interfere with them.
14. We used a mini USB connector which is common and used in most cell phones, so you do not have to buy other cables.
15. The original design did not space the connectors at 0.1", making perfboard use impossible. For compatibility, we used the same spacing but we added footprints next to the connectors on 0.1" which customers can use with perforated boards.
16. All signals on the connectors are printed on top and on bottom of the board, so when you check with a probe you know exactly which point you are measuring.

17. We added 4 mounting holes making board attachment easier.

### 1.3 Target market and purpose of the board

The board is aimed at beginners due to the fact it might be programmed without the need of third-party tools and the big Arduino community. It is also suitable for professionals due to the industrial range of operation, small form factor and wide power supply choice. The board is suitable for handheld applications.

### 1.4 Hardware revision of the board used in the manual

Revision B and revision C boards and resources were used while writing this document. It is possible that all revisions used to create the document are outdated so it is recommended to download the latest sources from the web-page of OLIMEXINO-328 at the official www.olimex.com web-site.

### 1.5 Document organization

Each section in this document covers a separate topic, organized as follow:

Chapter 1 is an overview of the board usage and features
Chapter 2 provides a guide for setting the board
Chapter 3 contains the general board diagram and layout
Chapter 4 mentions the control circuitry used in OLIMEXINO-328
Chapter 5 is an explanation of the connectors, the LEDs and the jumpers position Chapter 6 contains the general board diagram and layout
Chapter 7 contains the revision history, useful links and support information

### CHAPTER 2 - SETTING UP THE OLIMEXINO-328

### 2. Introduction to the chapter

This section helps you set up the OLIMEXINO-328 development board for the first time. Please consider first the electrostatic warning to avoid damaging the board, then discover the hardware and software required to operate the board.

The procedure to power up the board is given, and a description of the default board behavior is detailed.

### 2.1 Electrostatic warning

The OLIMEXINO-328 board is shipped in protective anti-static packaging. The board must not be subjected to high electrostatic potentials. General practice for working with static sensitive devices should be applied when working with this board.

### 2.2 Requirements

In order to set up the OLIMEXINO-328 optimally, you might need to update your set of hardware and/or software tools. The major needed components are listed below.

Hardware tools:

- USB type A to USB mini cable
- Personal computer with USB type A port

Software tools:

- any official Arduino IDE

You would need additional hardware and software if you want to use OLIMEXINO-328 as a general-purpose Atmel AVR board (or you want to reprogram the bootloader, required for Arduino IDE communication).

You would need to a have a working combination of a programmer tool and a software development environment. You would also need a 6-pin header or jumper wires to establish proper hardware connection between the programmer tool and the board.

Currently OLIMEX sells a couple of ATmega328-compatible programmers that would also work with the most common software environments (AVR Studio 4 and 5; Atmel Studio 6; AVRdude – the built-in Arduino programmer). These programmers are: AVR-ISP500 (https://www.olimex.com/Products/AVR/Programmers/AVR-ISP500/) and AVR-ISP-MK2. (https://www.olimex.com/Products/AVR/Programmers/AVR-ISP-MK2/)

### 2.3 Connecting to Arduino IDE

The latest Arduino IDE might be downloaded from the official Arduino web-site: http://arduino.cc.

After you have downloaded and installed (or extracted) the environment you should connect the OLIMEXINO-328 to the computer via an USB type A to USB mini cable.

The first time you connect the board you would be asked for drivers. You can find the drivers needed for OLIMEXINO-328 in the install folders of the Arduino IDE (usually in folder “drivers”).

After the drivers are successfully installed you should run the Arduino IDE.

In “Tools->Board” you should select “Arduino Duemilanove w/ ATmega328”.

That is all. Now you can load any built-in example or you can refer to the number of demo examples in the “SOFTWARE” section of the OLIMEXINO-328's web-page: https://www.olimex.com/Products/Duino/AVR/OLIMEXINO-328/

For more detailed instructions and Linux installation please check the following document: https://www.olimex.com/Products/Duino/AVR/OLIMEXINO-328/resources/Install_OLIMEXINO-328.pdf (https://www.olimex.com/Products/Duino/AVR/OLIMEXINO-328/resources/Install_OLIMEXINO-328.pdf)

### CHAPTER 3 - OLIMEXINO-328 BOARD DESCRIPTION

### 3. Introduction to the chapter

Here you get acquainted with the main parts of the board. Note the names used on the board differ from the names used to describe them. For the actual names, please, check the OLIMEXINO-328 itself.

### 3.1 Layout (top view)

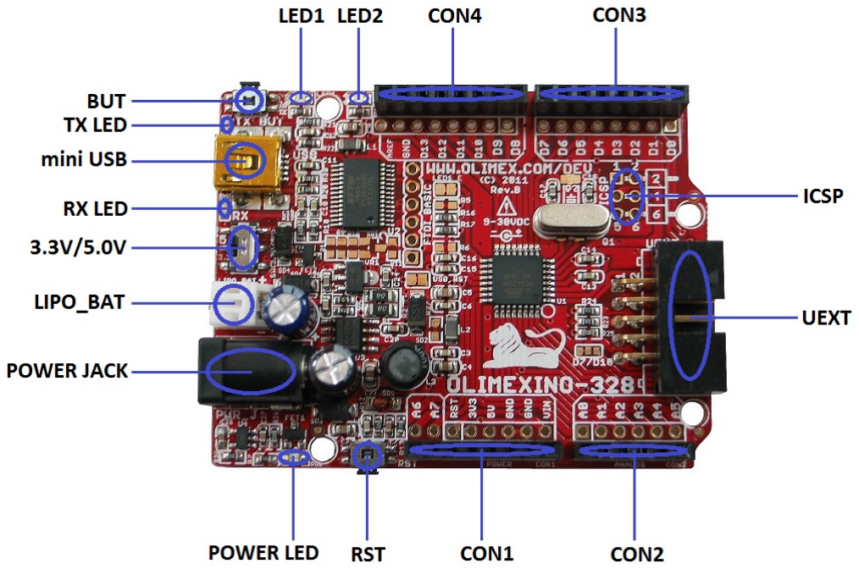
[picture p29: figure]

### 3.2 Layout (bottom view)

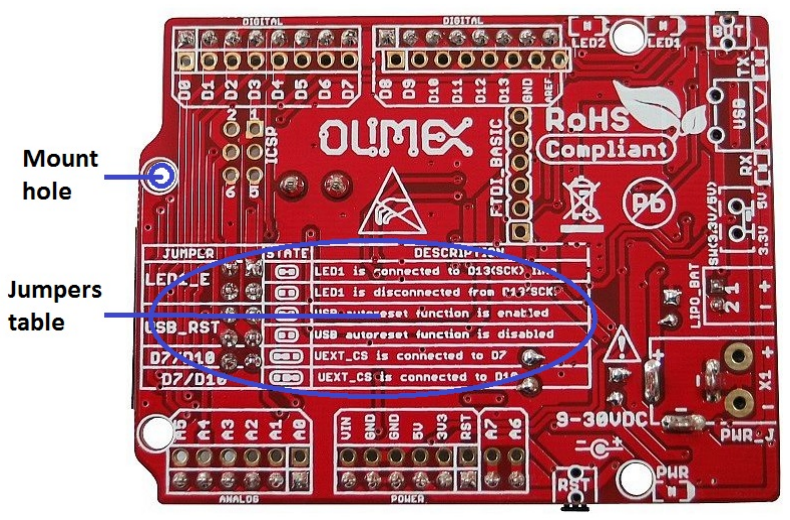
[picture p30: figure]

### CHAPTER 4 - CONTROL CIRCUITY

### 4. Introduction to the chapter

Here you can find information about reset circuit and quartz crystals locations, the power supply circuit is discussed.

### 4.1 Reset

OLIMEXINO-328 reset circuit includes R12 (4.7kΩ), R13 (330Ω), SD5 (1N4148), C7 (4.7nF), C8(100nF), jumper USB_RST, ATmega328P pin29 (PC6/3RESET/PCINT14) and RST button.

### 4.2 Clocks

Quartz crystal Q1 16 MHz is connected to ATmega328P pin 7 (XTAL1) and pin 8 (XTAL2). Note that the crystal is on socket and can be changed to any value.

### 4.3 Power supply circuit

OLIMEXINO-328 can take power supply from:

- external power supply (9-30) VDC.
- +5V from USB
- 3.7V Li-ion battery

The programmed board power consumption is about 20mA with all peripherals enabled.

### CHAPTER 5 - INTERFACES AND HARDWARE

### 5. Introduction to the chapter

In this chapter are presented the interfaces found on the programmed that can be found on the board. Jumpers functions are described.

### 5.1 UEXT connector

The UEXT is used to connect additional extension modules to the OLIMEXINO-328. Most Olimex extensions (named MOD-XXXX) can be plugged directly to this connector. If you wish to add additional extras to your board this is the right interface. Of course, using jumper wires you might connect any other board that uses I2C, SPI or UART interface without the need of soldering.

More information about the UEXT might be found here: https://www.olimex.com/Products/Modules/UEXT/

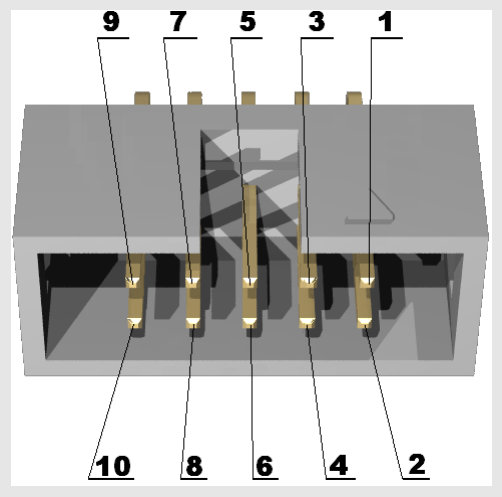
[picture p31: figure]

Pin # | Signal name
1 | VCC
2 | GND
3 | D1(TXD)
4 | D0(RXD)
5 | A5(SCL)
6 | A4(SDA)
7 | D12(MISO)
8 | D11(MOSI)
9 | D13(SCK/LED1)
10 | UEXT_#CS

### 5.2 PWR_J connector

The power jack used is the typical 2.5mm one used by Olimex in most of our products. You should provide between 6 and 16 volts @ 1.5A maximum to the board.

Note that we also sell a couple of compatible 12V capable power supplies suitable for European customers. These might be found here: https://www.olimex.com/Products/Power/.

Pin # | Signal name
1 | Power Input
2 | GND

### 5.3 Arduino shield platform

These four connectors are usually used when you want to mount extension shield on the OLIMEXINO-328. The shield connector layout follows the original Arduino layout and spacing BUT we have also provided set of metalized holes that improve the layout by keeping 0.1'' step between connectors. The extra holes might be used when the original connector get clunky of wires. They can be used for placing measuring tools.

Olimex has a number of shields available. They might be found here: https://www.olimex.com/Products/Duino/Shields/

### 5.3.1 CON1 – POWER

Pin # | Signal name
1 | RESET
2 | +3.3V
3 | +5V
4 | GND
5 | GND
6 | VIN

### 5.3.2 CON2 – ANALOG

Pin # | Signal name
1 | A0
2 | A1
3 | A2
4 | A3
5 | A4(SDA)
6 | A5(SCL)

### 5.3.3 CON3 – DIGITAL

Pin # | Signal name
1 | D0(RXD)
2 | D1(TXD)
3 | D2(BUT)
4 | D3
5 | D4
6 | D5
7 | D6
8 | D7

Note: There is a capacitor C12 connected to D2 and in parallel to BUT (for filtering bounces of the BUT) but it can cause interference (and unwanted filtering of signals) if you want to connect for instance RF module to D2, remove C12.

### 5.3.4 CON4 – DIGITAL:

Note that the additional pads near the CON4 seems slightly off due to the improvement of the shield design we have made. Consider this alignment when referring to the white print on the board.

Pin # | Signal name
1 | D8
2 | D9
3 | D10(#SS)
4 | D11(MOSI)
5 | D12(MISO)
6 | D13(SCK/LED1)
7 | GND
8 | AREF

### 5.4 LIPO_BAT connector

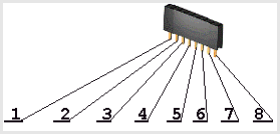
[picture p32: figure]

The LIPO_BAT connector comes handy when you want to use the OLIMEXINO-328 as a stand-alone device.

Pin # | Signal name
1 | VBAT
2 | GND

Olimex LTD has a number of batteries with the proper connector. They might be found here: https://www.olimex.com/Products/Power/

### 5.4 mini USB connector

Pin # | Signal name
1 | +5V_VBUS (VCCINT)
2 | USBDM
3 | USBDP
4 | Not connected
5 | GND

### 5.5 ICSP pads

Pin # | Signal name
1 | D12(MISO)
2 | VCC
3 | D13(SCK/LED1)
4 | D11(MOSI)
5 | RESET
6 | GND

Note, that there is no plastic component mounted for this connector. You would either need own connector or jumper wires to be able to connect your AVR programmer tool.

Please make sure you are not trying to use TPI or PDI interface with the ICSP pads.

If your programmer has only 10 pin ICSP cable you would need to use jumper wires or adapter to be able to connect to the 6 pin interface.

### 5.6 Jumper description

The pictures below show the default jumper position. Note that the board has only SMT jumpers which require soldering to close the jumper; and melting the solder plus cutting between the pads to disconnect the jumper.

### 5.6.1 USB_RST jumper

When closed USB_RST jumper enables USB auto-reset function. After reset the bootloader is started and loads the program into the Flash.

Default state is closed.

### 5.6.2 LED1_E jumper

When closed LED1_E, connects LED1 to D13(SCK) line.

Default state is closed.

### 5.6.2 D7/D10 jumper

When D7/D10 jumper is closed in position D7 – UEXT pin 10 (UEXT_CS) is connected to Atmega328P pin 11 (PD7) – signal D7, when this jumper is closed in position D10 - UEXT pin 10 (UEXT_CS) is connected to Atmega328P pin 14 (PB2/#SS) – signal D10(3SS).

Default state is closed in position D7.

### 5.7 LEDs and buttons:

Status LED with name LED1 (green) connected via jumper LED1_E to ATmega328P pin 17

(SCK/PCINT5/PB5) – signal D13(SCK/LED1).

Status LED with name LED2 (yellow) connected to ATmega328P pin 13 (PCINT1/OC1A/PB1) – signal D9(LED2).

Status LED with name TX (red) indicates that there is transfer in the FTDI.

Status LED with name RX (green) indicates that there is transfer in the FTDI.

Power-on LED (red) with name PWR – this LED shows that the board is power supplied.

User button with name BUT connected to ATmega328P pin 32 (INT0/PCINT18/PD2) – signal D2(BUT).

User button with name RST connected to ATmega328P pin 29 (PC6/#RESET).

Switch with name SW(3.3V/5V) – selects between 3.3V and 5V power supply of the board.

### CHAPTER 6 - SCHEMATICS

### 6. Introduction to the chapter

In this chapter is located information about the schematics describing logically and physically OLIMEXINO-328.

### 6.1 Eagle schematics

Stand-alone search-able schematic in PDF format might be found at the web page of OLIMEXINO-328.

The schematic is also shown on the next page for quicker reference.

We mostly use Eagle by Cad Soft 4.16r2 for designing. However, the files should be compatible with the latest Eagle available. Cad Soft offers a trial version of their software that allows you to inspect schematics and board files (without being able to modify them).

This work is licensed under the Creative Commons Attribution-ShareAlike 3.0 Unported License. To view a copy of this license, visit http://creativecommons.org/licenses/by-sa/3.0/.

OLIMEX© 2013 | OLIMEXINO-328 user's manual

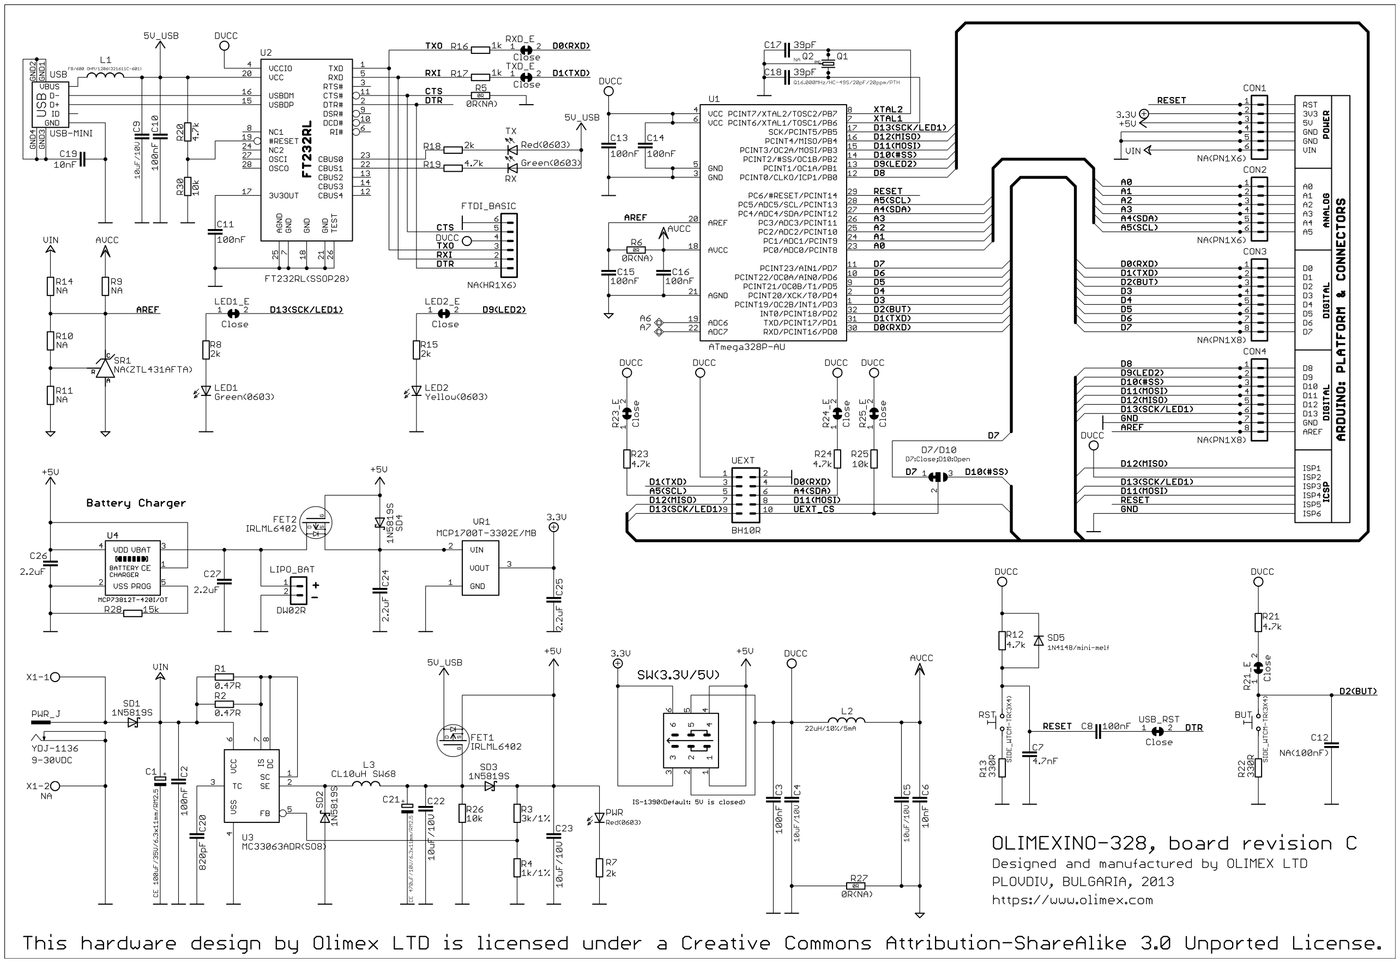
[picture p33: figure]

Page 19 of 23

### 6.2 Physical dimensions

Note that all dimensions are in inches.

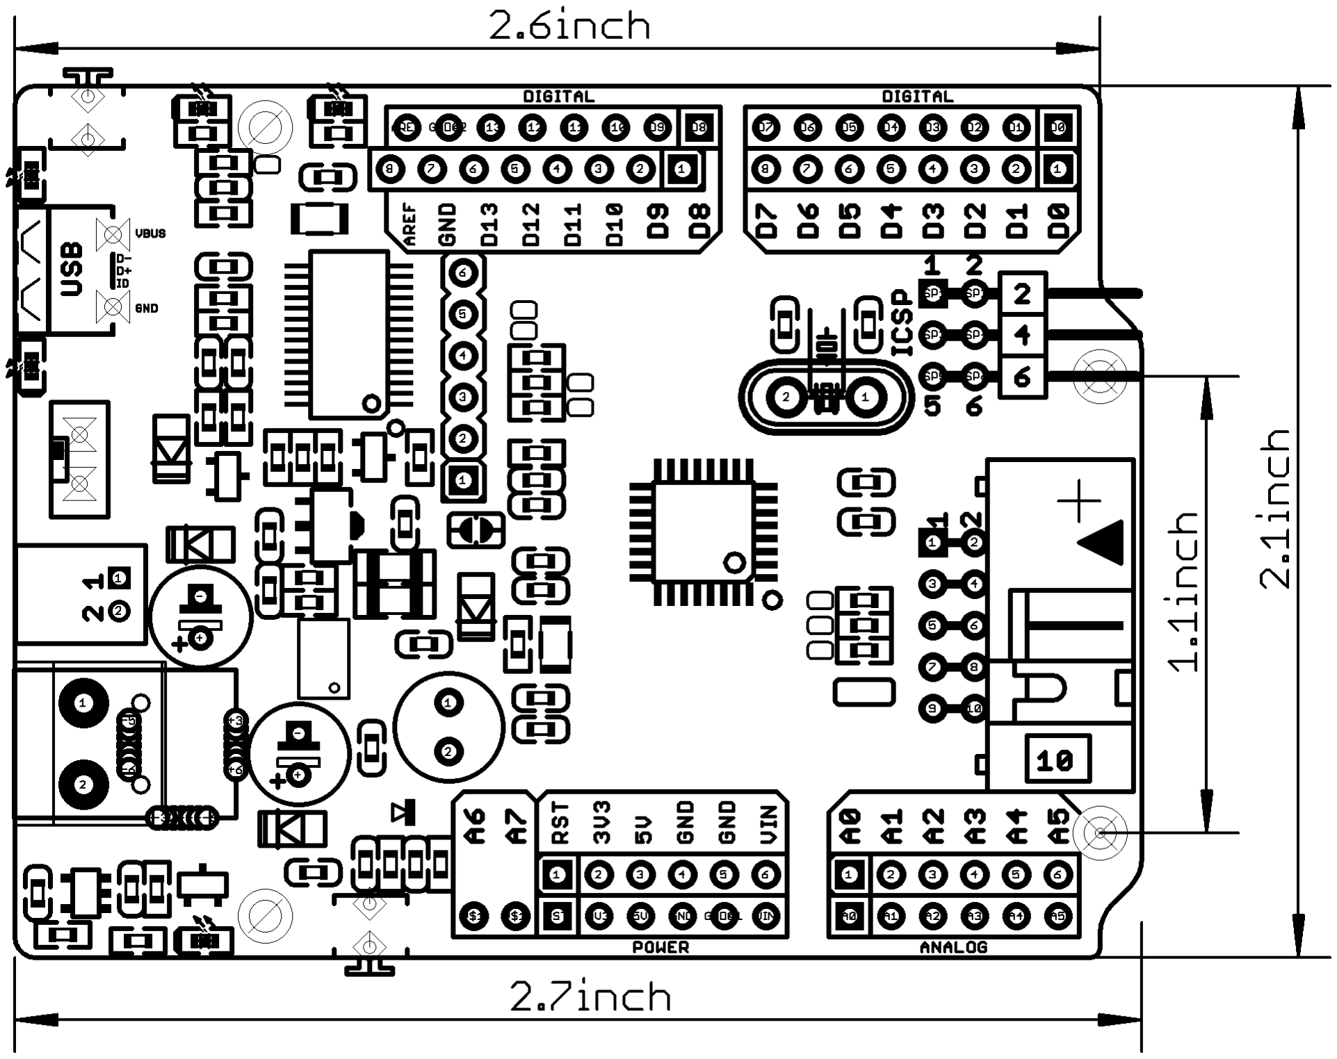
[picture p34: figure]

### CHAPTER 7 - REVISION HISTORY AND SUPPORT

### 7. Introduction to the chapter

In this chapter you will find the current and the previous version of the document you are reading. Also the web-page for your device is listed. Be sure to check it after a purchase for the latest available updates and examples.

### 7.1 Document revision

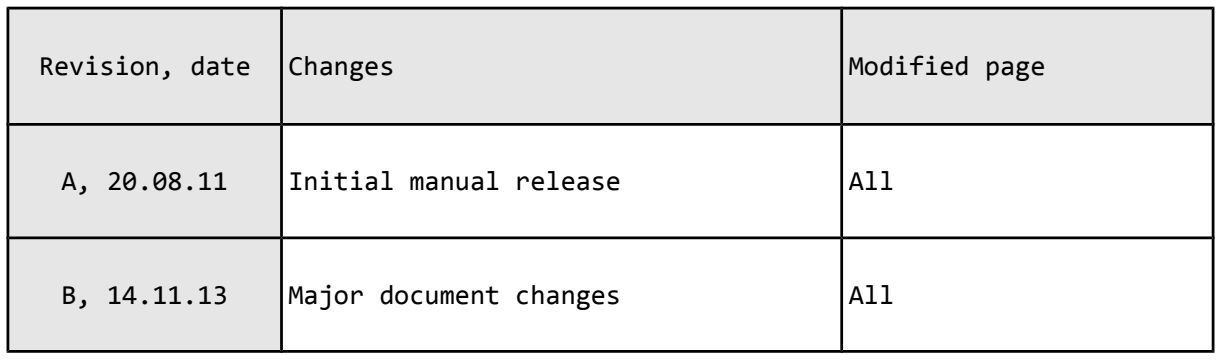
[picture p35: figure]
Revision, date; Changes; Modified page; Initial manual release; All; Major document changes

### 7.2 Board revision

Remember to check the schematics and the board design files to compare the differences.

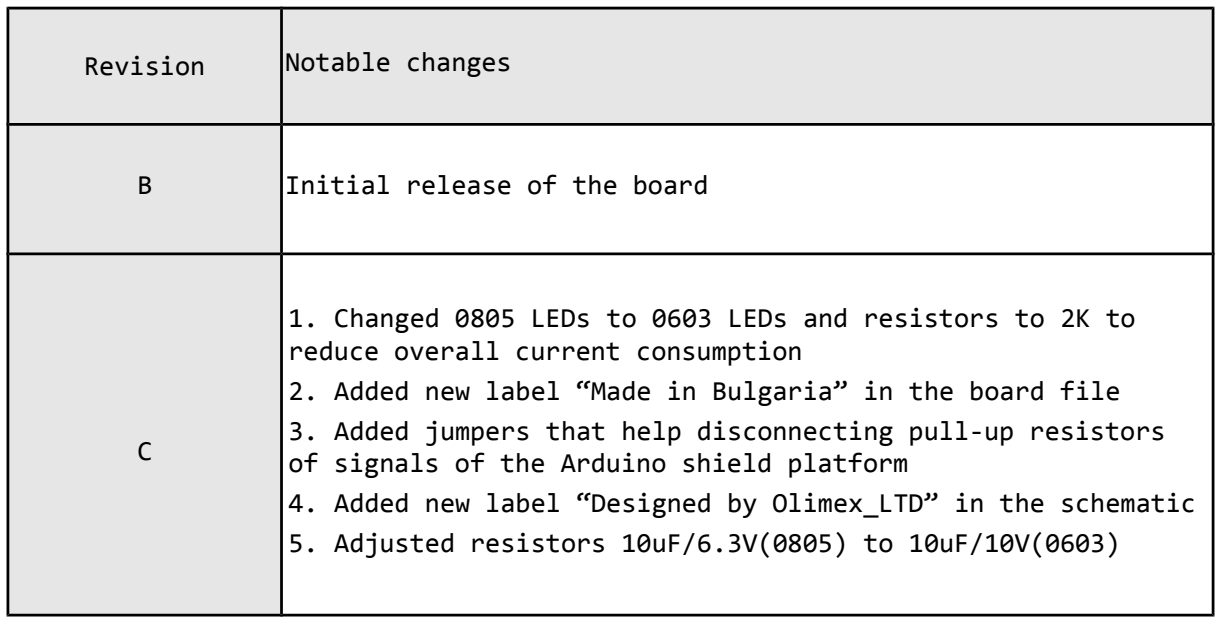
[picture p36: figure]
Revision; Notable changes; Initial release of the board; reduce overall current consumption

1. Changed 0805 LEDs to 0603 LEDs and resistors to 2K to
2. Added new label “Made in Bulgaria” in the board file
3. Added jumpers that help disconnecting pull-up resistors of signals of the Arduino shield platform
4. Added new label “Designed by Olimex_LTD” in the schematic
5. Adjusted resistors 10uF/6.3V(0805) to 10uF/10V(0603)

### 7.3 Useful web links and purchase codes

The web page you can visit for more info on your device is https://www.olimex.com/Products/Duino/AVR/OLIMEXINO-328/.

For more info on the original Arduino design please visit: http://arduino.cc/en/Main/arduinoBoardDuemilanove.

ORDER CODES:

OLIMEXINO-328 - assembled and tested Arduino-like board

AVR-ISP500 – assembled and tested AVR-ISP compatible programmer

AVR-ISP-MK2 – assembled and tested AVR-ISP compatible programmer

How to purchase Olimex products?

You can order from our web-shop or from any of our distributors. The list of official Olimex distributors might be found at: https://www.olimex.com/Distributors/.

Please check https://www.olimex.com/ for more info.

### 7.4 FAQ

Q1: I installed the OLIMEXINO-328 drivers. The board shows in “Windows Device Manager” correctly. Yet, the board cannot be programmed in Arduino IDE?

A1. Try installing older FTDI drivers. FTDI drivers 2.08.14 or earlier should fix the issue. The problem with the FTDI drivers is described in this forum post: https://www.olimex.com/forum/index.php?topic=2031.0.

Q2: I have OLIMEXINO-328 and Olimex AVR-ISP-MK2. The drivers seem correct, yet I'm unable to program the board. What might be causing the problem?
A2: Very often people try to use the PDI or TPI interface of AVR-ISP-MK2 for the ICSP slot of OLIMEXINO-328. Please, use jumper wires to transform the 10-pin ICSP of the AVR-ISP-MK2 to 6-pin ICSP connector of the OLIMEXINO-328.

### 7.5 Product support

For product support, hardware information and error reports mail to: support@olimex.com. All document or hardware feedback is welcome. Note that we are primarily a hardware company and our software support is limited. Please consider reading the paragraph below about the warranty of Olimex products.

All goods are checked before they are sent out. In the unlikely event that goods are faulty, they must be returned, to OLIMEX at the address listed on your order invoice.
OLIMEX will not accept goods that have clearly been used more than the amount needed to evaluate their functionality.

If the goods are found to be in working condition, and the lack of functionality is a result of lack of knowledge on the customers part, no refund will be made, but the goods will be returned to the user at their expense.

All returns must be authorized by an RMA Number. Email support@olimex.com for authorization number before shipping back any merchandise. Please include your name, phone number and order number in your email request.

Returns for any unaffected development board, programmer, tools, and cables permitted within 7 days from the date of receipt of merchandise. After such time, all sales are considered final.

Returns of incorrect ordered items are allowed subject to a 10% restocking fee. What is unaffected? If you hooked it to power, you affected it. To be clear, this includes items that have been soldered to, or have had their firmware changed. Because of the nature of the products we deal with (prototyping electronic tools) we cannot allow returns of items that have been programmed, powered up, or otherwise changed post shipment from our warehouse.

All returned merchandise must be in its original mint and clean condition. Returns on damaged, scratched, programmed, burnt, or otherwise 'played with' merchandise will not be accepted.

All returns must include all the factory accessories which come with the item. This includes any In-Circuit-Serial-Programming cables, anti-static packing, boxes, etc.

With your return, enclose your PO#. Also include a brief letter of explanation of why the merchandise is being returned and state your request for either a refund or an exchange. Include the authorization number on this letter, and on the outside of the shipping box.

Please note: It is your responsibility to ensure that returned goods reach us. Please use a reliable form of shipping. If we do not receive your package we will not be held liable.

Shipping and handling charges are not refundable. We are not responsible for any shipping charges of merchandise being returned to us or returning working items to you.

The full text might be found at https://www.olimex.com/wiki/GTC#Warranty for future reference.

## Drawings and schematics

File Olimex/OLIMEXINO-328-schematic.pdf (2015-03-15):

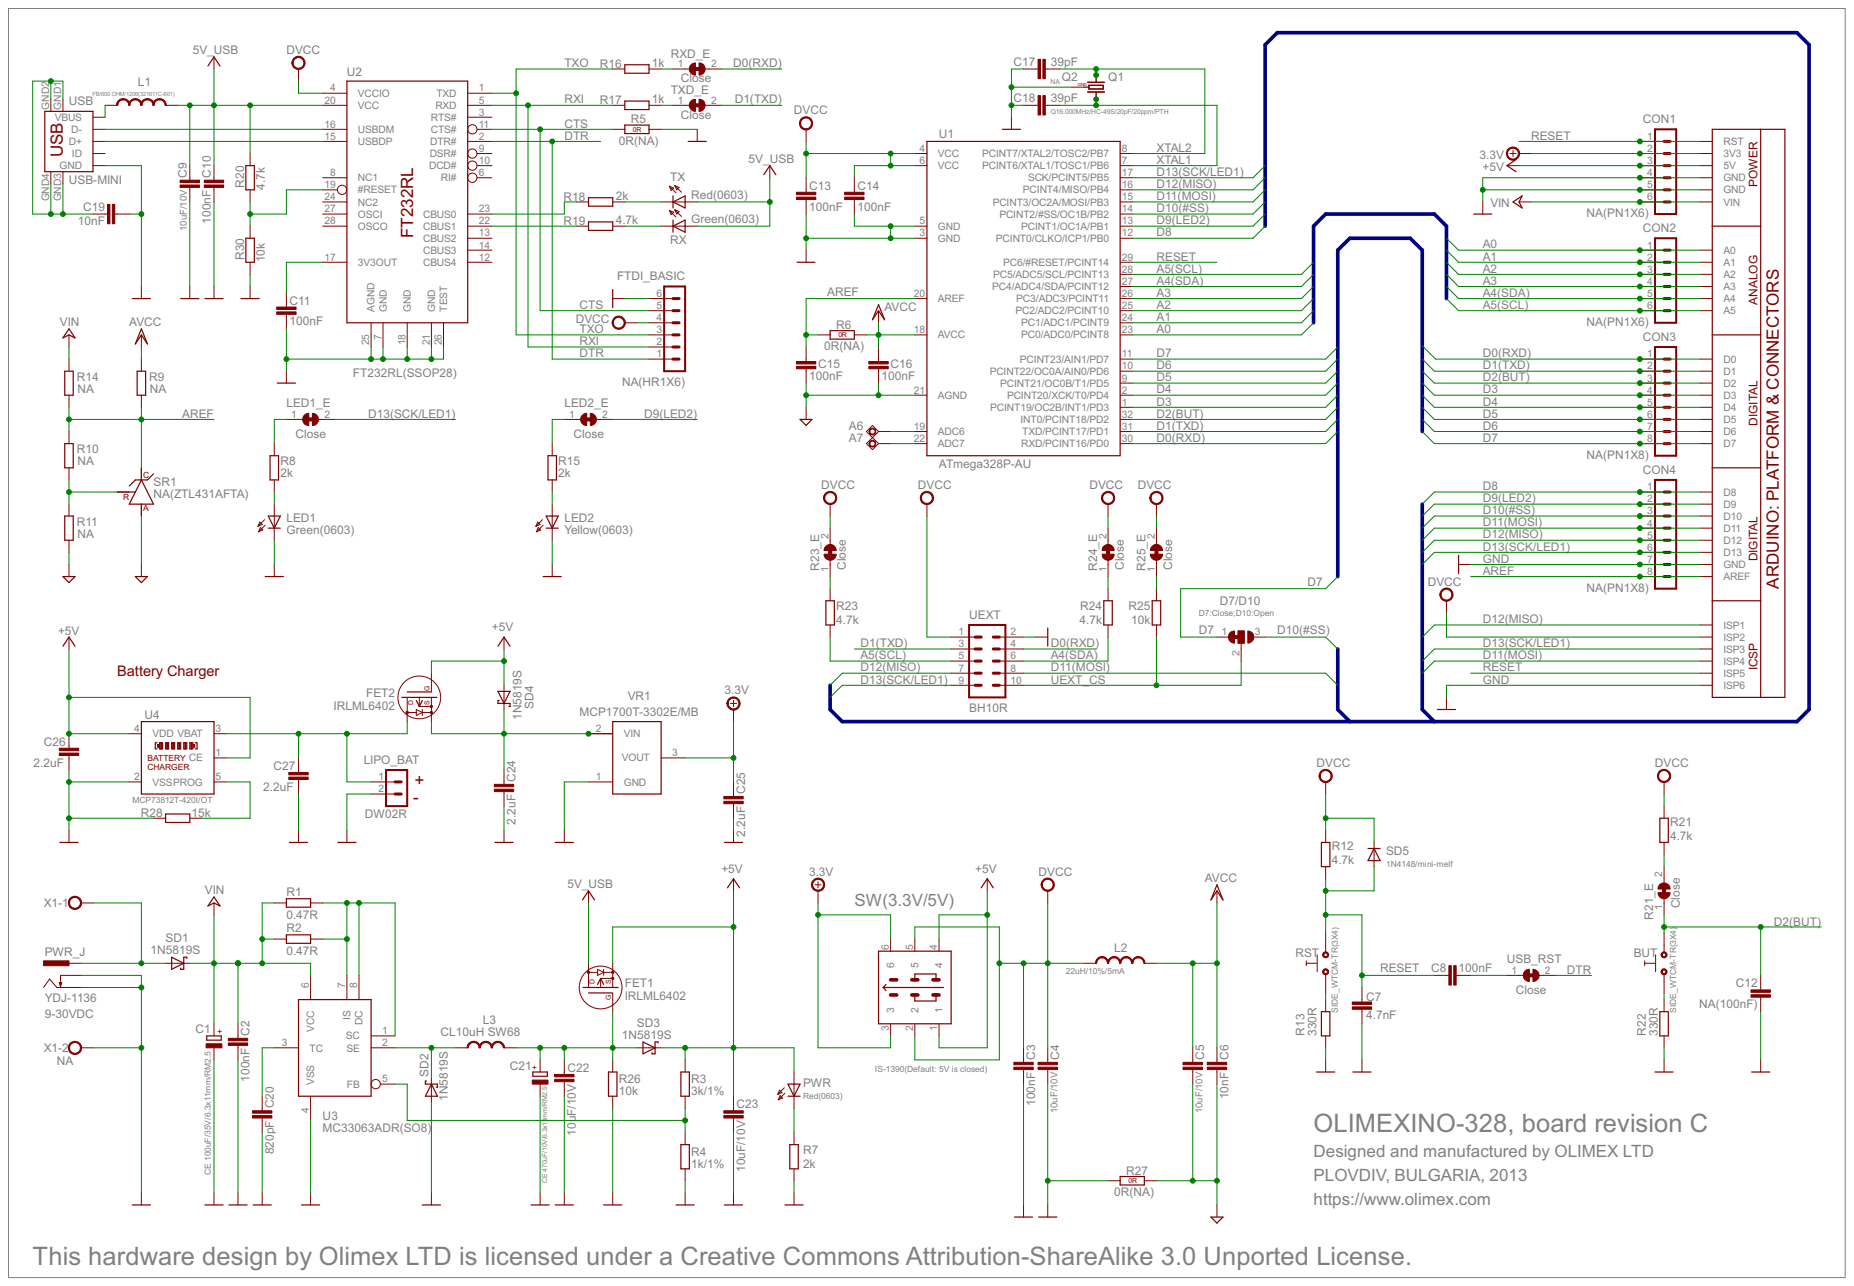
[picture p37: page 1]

POWER ANALOG DIGITAL DIGITAL ARDUINO: PLATFORM & CONNECTORS

IS-1390(Default: 5V is closed)

Designed and manufactured by OLIMEX LTD
PLOVDIV, BULGARIA, 2013

https://www.olimex.com This hardware design by Olimex LTD is licensed under a Creative Commons Attribution-ShareAlike 3.0 Unported License.

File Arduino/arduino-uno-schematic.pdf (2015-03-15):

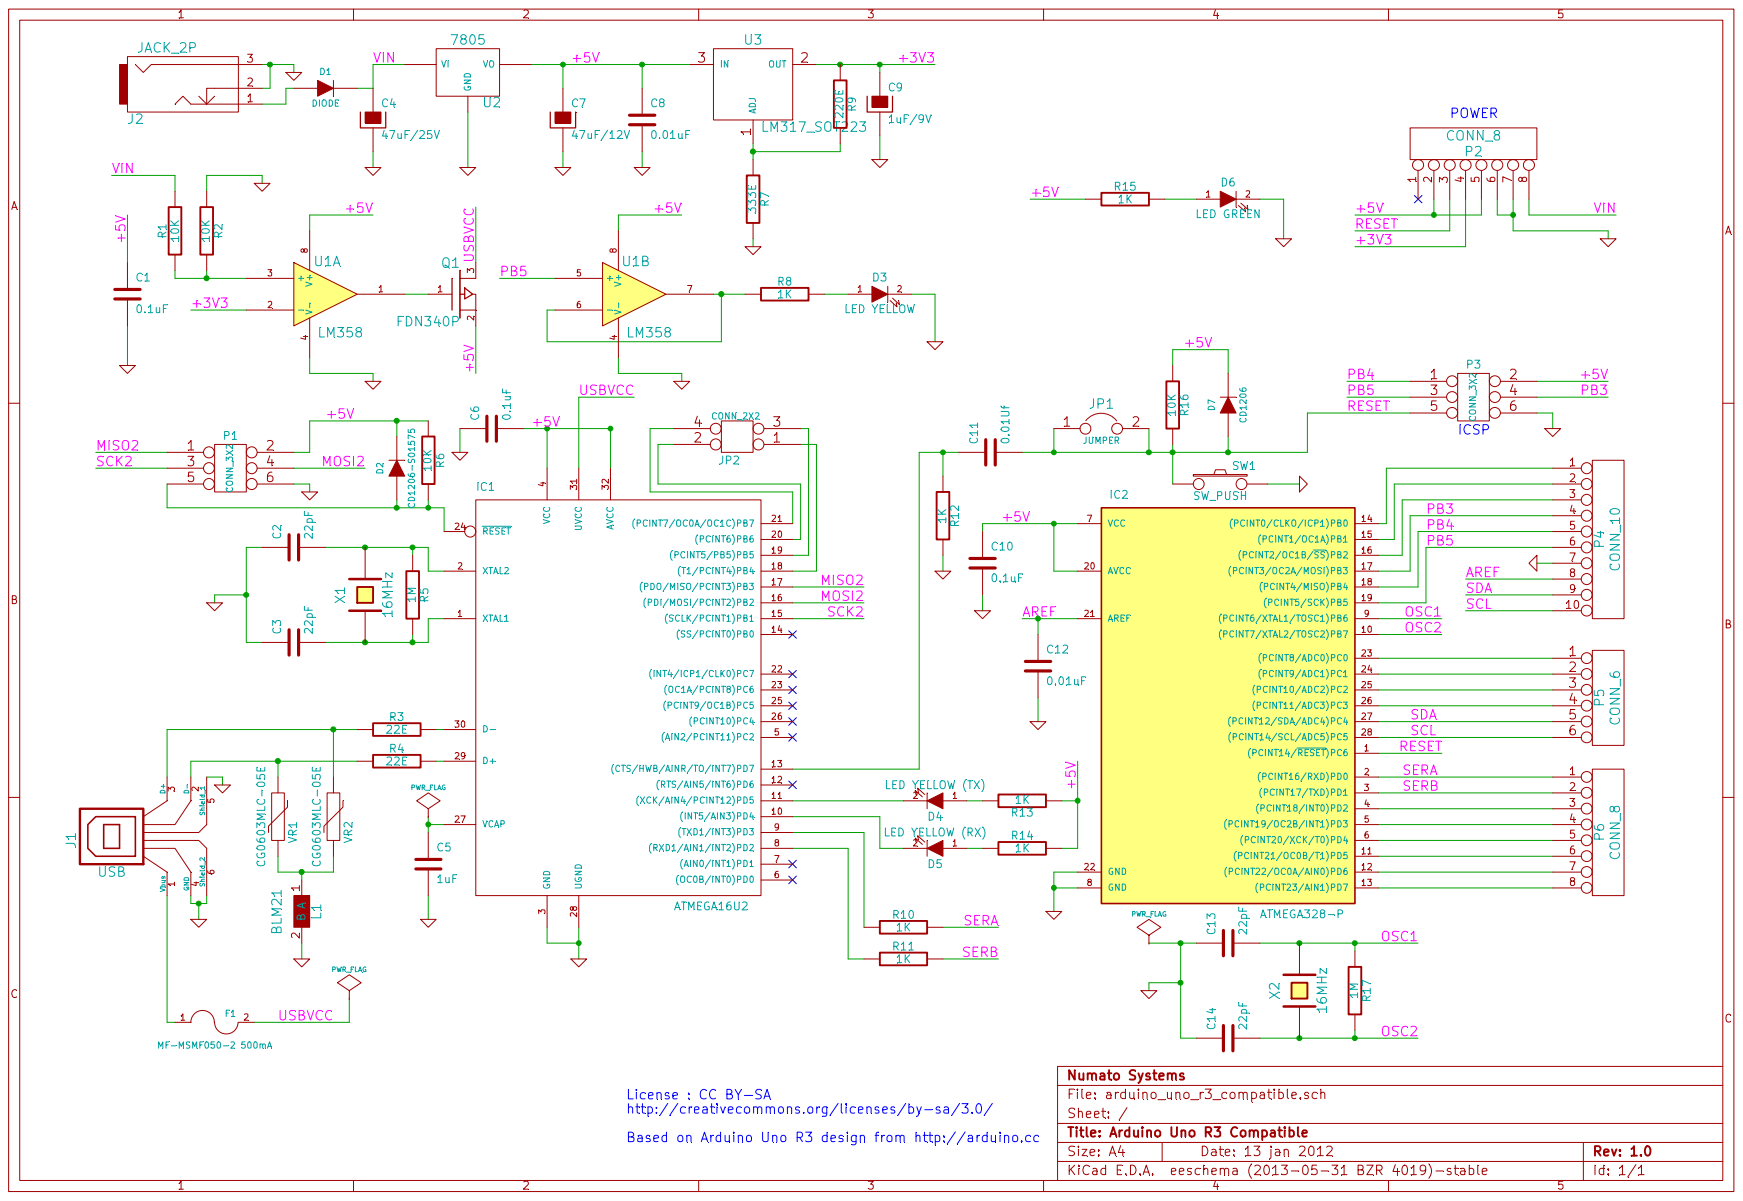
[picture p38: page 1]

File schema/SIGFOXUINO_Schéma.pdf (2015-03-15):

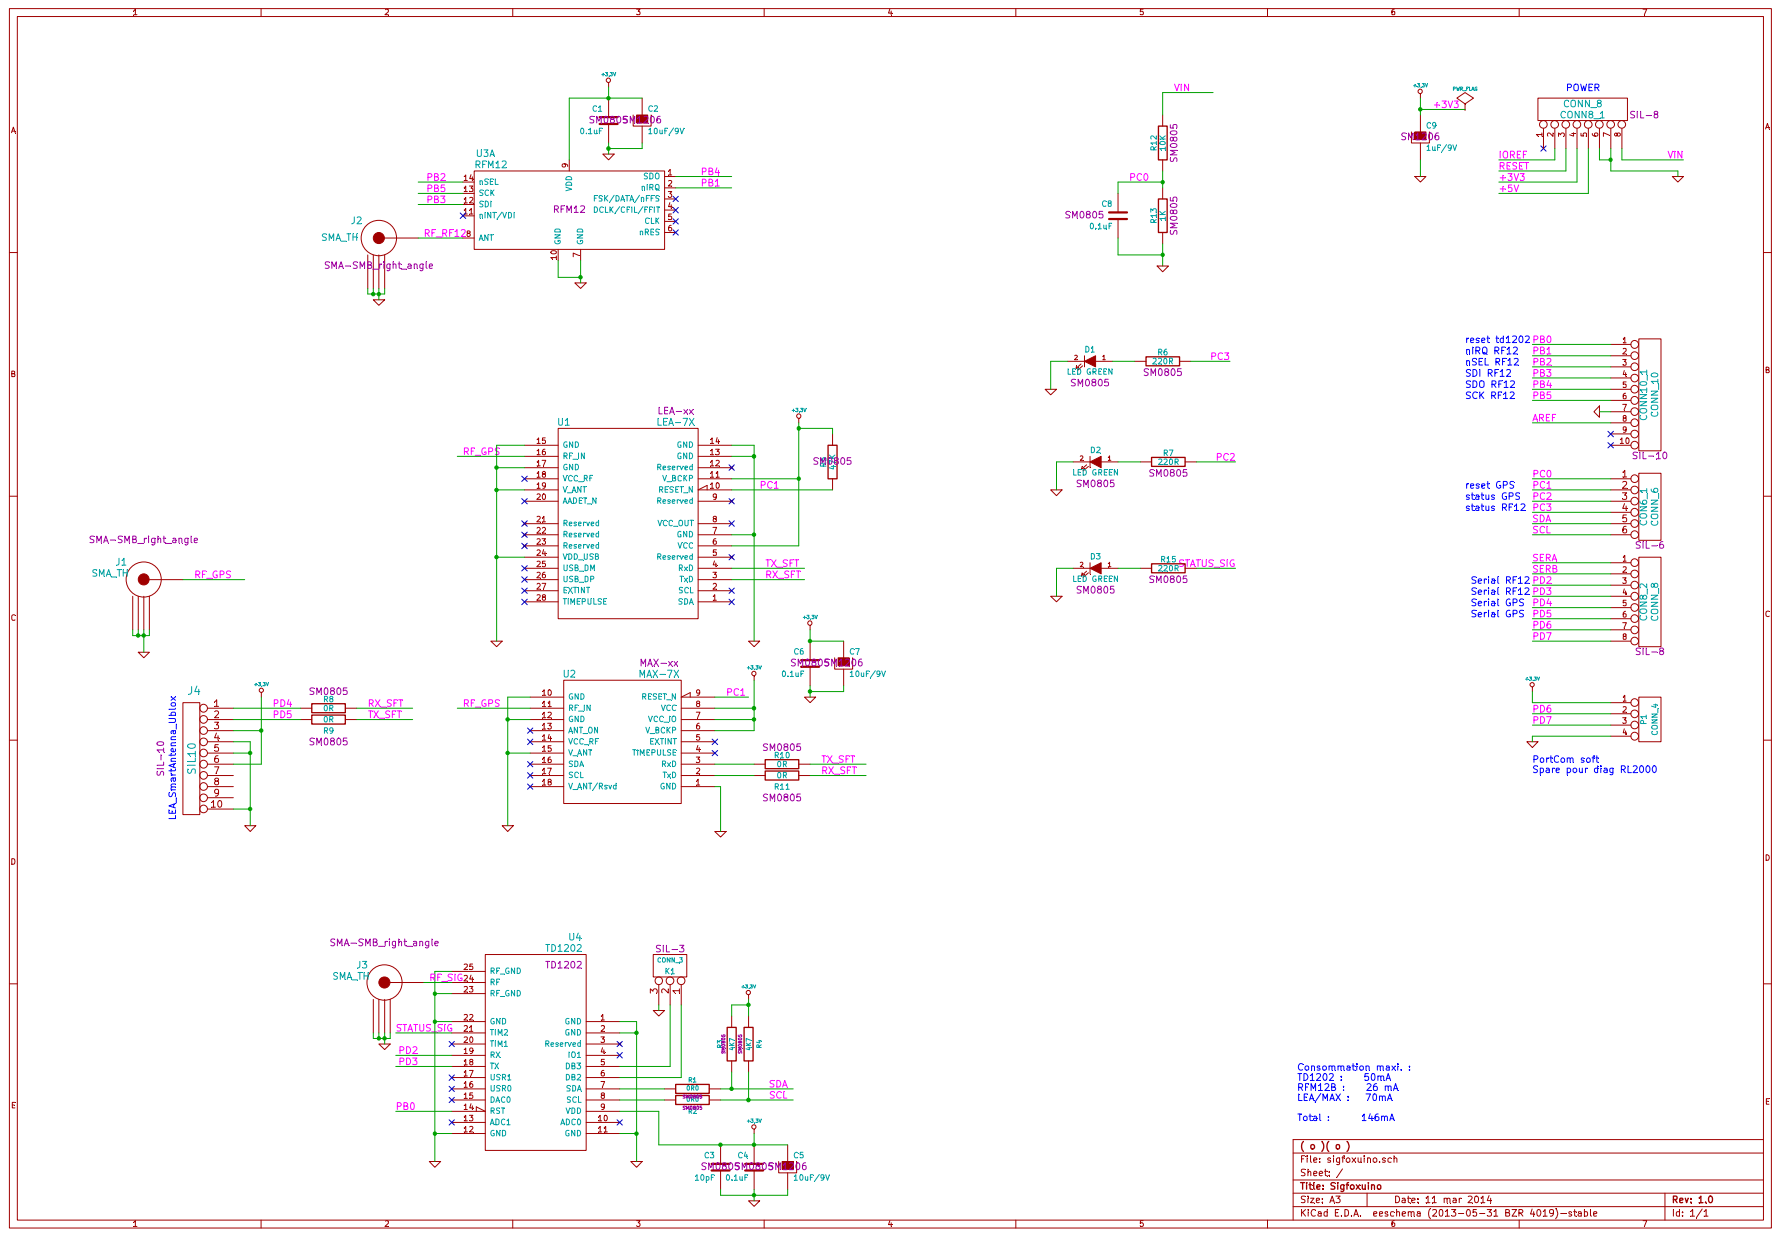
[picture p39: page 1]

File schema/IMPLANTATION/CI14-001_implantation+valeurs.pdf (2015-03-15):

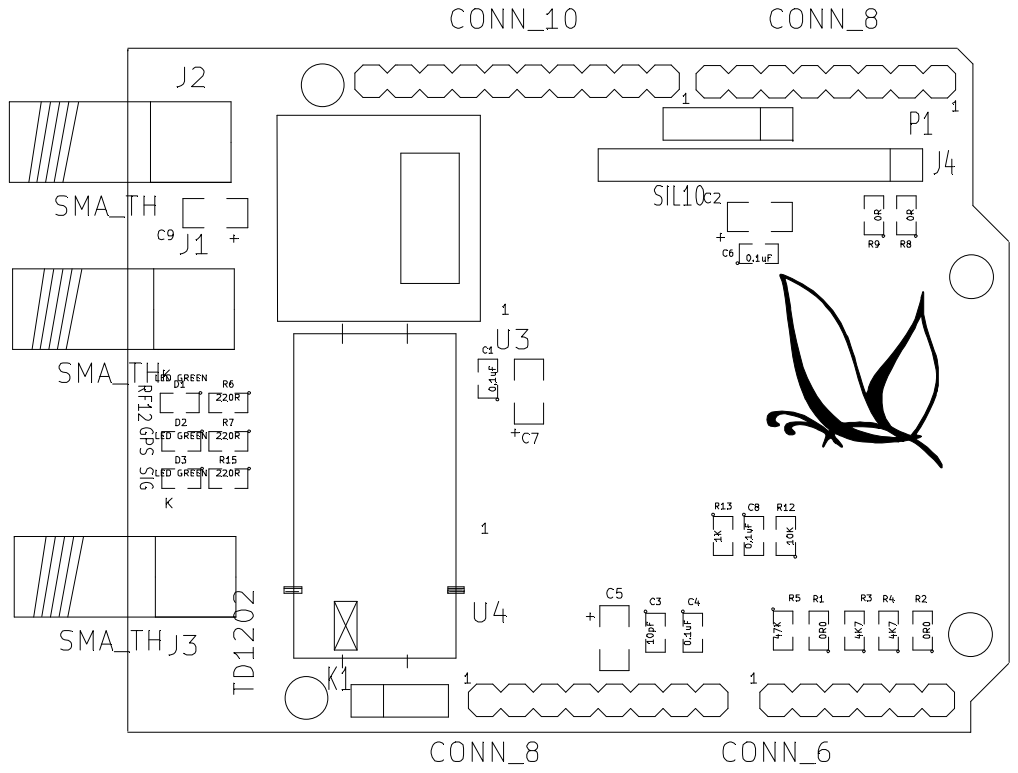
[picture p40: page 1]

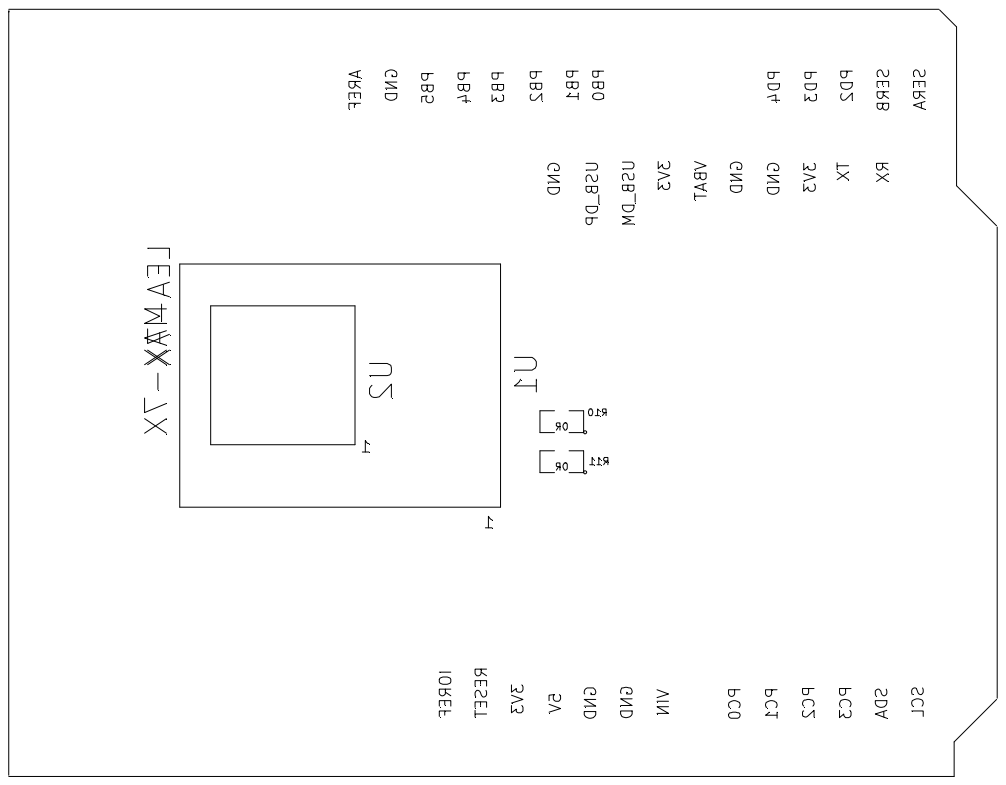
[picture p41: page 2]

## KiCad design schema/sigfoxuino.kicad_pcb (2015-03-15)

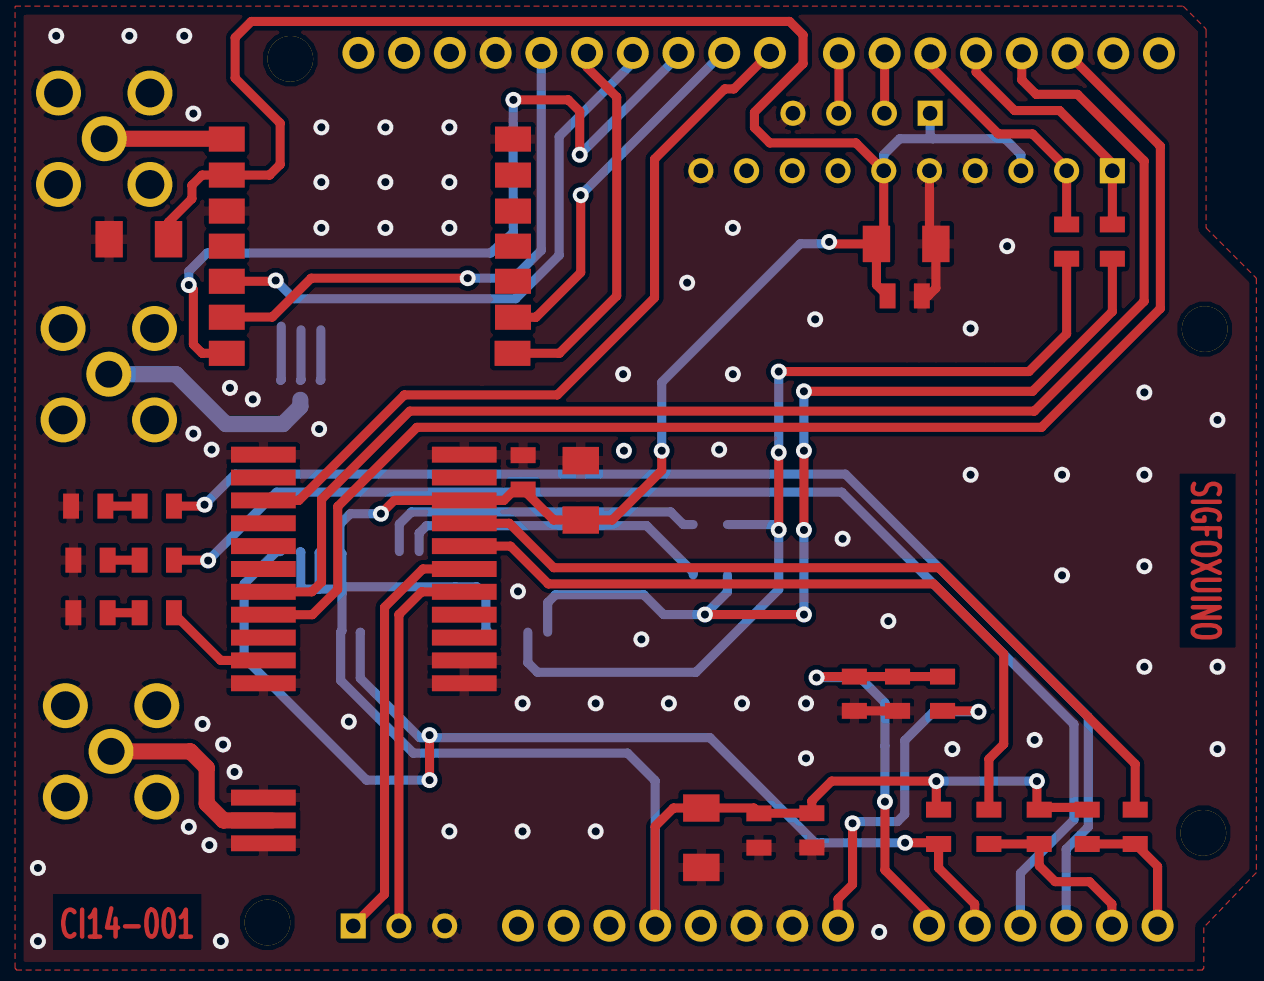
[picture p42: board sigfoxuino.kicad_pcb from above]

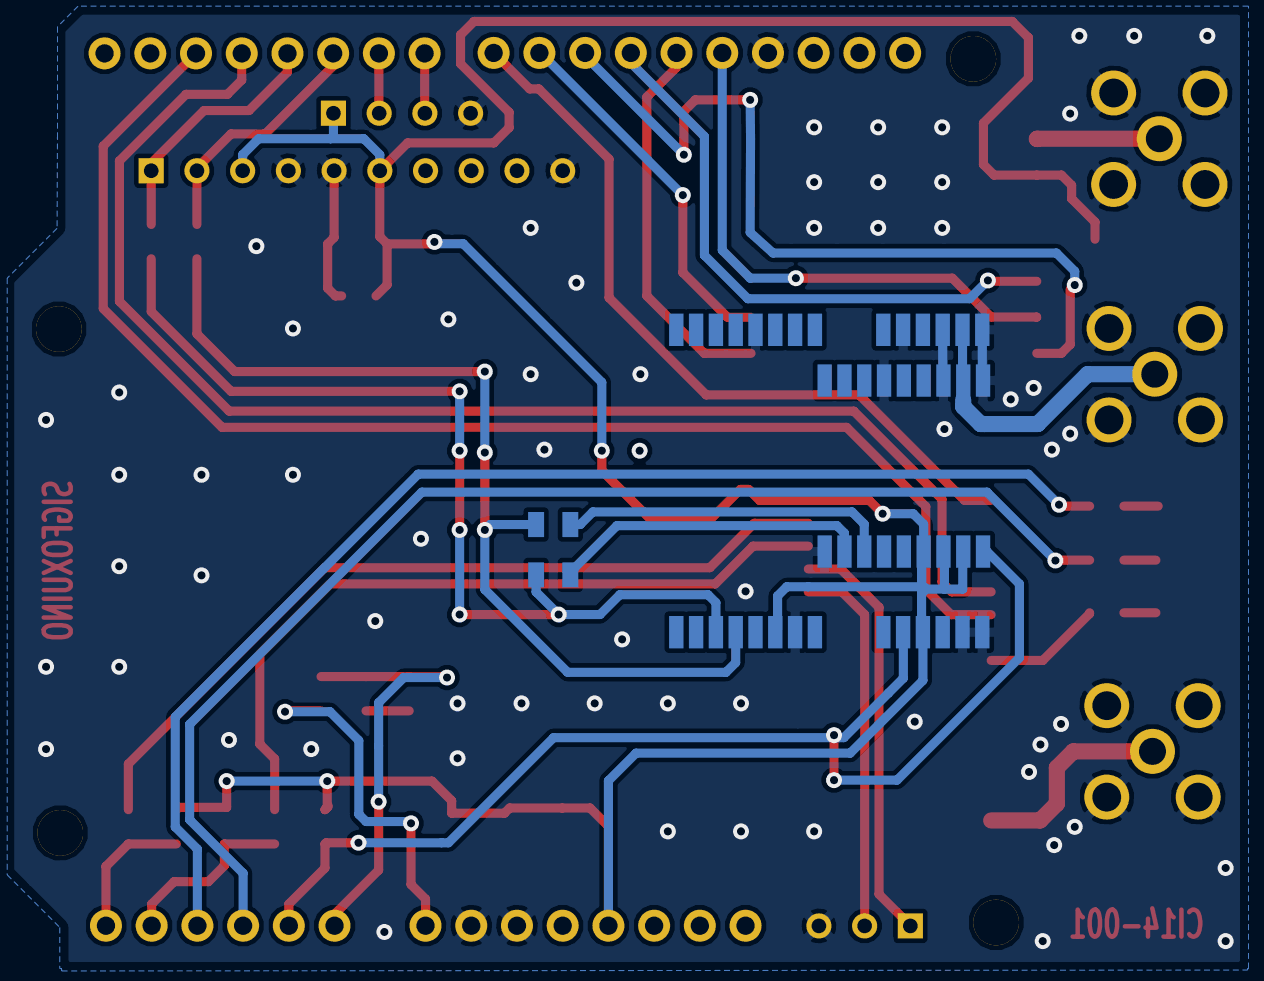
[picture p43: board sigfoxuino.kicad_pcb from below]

Board: 2 copper layers, 42 parts (4 on the bottom side), 36 nets.

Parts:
C1, C4, C6, C8: 0.1uF; SM0805
C2, C5, C7: 10uF/9V; SM1206
C3: 10pF; SM0805
C9: 1uF/9V; SM1206
CON6_1: CONN_6; Con6
CON8_2: CONN_8; Con8
CONN8_1: CONN_8; Con8
CONN10_1: CONN_10; Con10
D1, D2, D3: LED GREEN; SM0805
J1, J2, J3: SMA_TH; SMA-SMB_right_angle
J4: SIL10; SIL-10
K1: CONN_3; SIL-3
P1: CONN_4; SIL-4
R1, R2: 0R0; SM0805
R3, R4: 4K7; SM0805
R5: 47K; SM0805
R6, R7, R15: 220R; SM0805
R8, R9, R10, R11: 0R; SM0805
R12: 10K; SM0805
R13: 1K; SM0805
U1: LEA-7X; LEA-xx
U2: MAX-7X; MAX-xx
U3: RFM12
U4: TD1202
V4, V5: 1pin

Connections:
+3.3V: C1.1, C2.1, C3.1, C4.1, C5.1, C6.1, C7.1, C9.1, CONN8_1.4, J4.3, J4.6, P1.1, R3.2, R4.2, R5.1, U1.6, U1.11, U2.6, U2.7, U2.8, U3.9, U4.9
/PB0: CONN10_1.1, U4.14
/PB1: CONN10_1.2, U3.2
/PB2: CONN10_1.3, U3.14
/PB3: CONN10_1.4, U3.12
/PB4: CONN10_1.5, U3.1
/PB5: CONN10_1.6, U3.13
/PC0: C8.1, CON6_1.1, R12.2, R13.1
/PC1: CON6_1.2, R5.2, U1.10, U2.9
/PC2: CON6_1.3, R7.1
/PC3: CON6_1.4, R6.1
/PD2: CON8_2.3, U4.19
/PD3: CON8_2.4, U4.18
/PD4: CON8_2.5, J4.1, R8.2
/PD5: CON8_2.6, J4.2, R9.2
/PD6: CON8_2.7, P1.2
/PD7: CON8_2.8, P1.3
/RF_GPS: J1.1, U1.16, U2.11
/RF_RF12: J2.1, U3.8
/RF_SIG: J3.1, U4.24
/RX_SFT: R8.1, R11.1, U1.3
/SCL: CON6_1.6, R2.1, R4.1
/SDA: CON6_1.5, R1.1, R3.1
/STATUS_SIG: R15.1, U4.21
/TX_SFT: R9.1, R10.1, U1.4
/VIN: CONN8_1.8, R12.1
GND: C1.2, C2.2, C3.2, C4.2, C5.2, C6.2, C7.2, C8.2, C9.2, CONN8_1.6, CONN8_1.7, CONN10_1.7, D1.2, D2.2, D3.2, J1.2, J1.3, J1.4, J1.5, J2.2, J2.3, J2.4, J2.5, J3.2, J3.3, J3.4, J3.5, J4.4, J4.5, J4.10, K1.3, P1.4, R13.2, U1.7, U1.13, U1.14, U1.15, U1.17, U1.19, U1.24, U2.1, U2.10, U2.12, U2.15, U3.7, U3.10, U4.1, U4.2, U4.11, U4.12, U4.22, U4.23, U4.25
unnamed: R11.2, U2.2
unnamed: R10.2, U2.3
unnamed: D2.1, R7.2
unnamed: D1.1, R6.2
unnamed: K1.2, U4.5
unnamed: K1.1, U4.6
unnamed: D3.1, R15.2
unnamed: R2.2, U4.8
unnamed: R1.2, U4.7

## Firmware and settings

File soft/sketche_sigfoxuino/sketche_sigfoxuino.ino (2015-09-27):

//--------------------------------------------------
//! \file		sketche_sigfoxuino.ino
//! \brief		SIGFOX GPS TRACKER
//! \brief		Use GPS for localisation.
//! \brief		TD1202 SIGFOX module

//! \brief		Receives from the hardware serial, sends to software serial.
//! \brief		Receives from software serial, sends to hardware serial.
//! \brief		The circuit:
//! \brief		* RX is digital pin 3 (connect to TX of TD1202)
//! \brief		* TX is digital pin 2 (connect to RX of TD1202)
//! \brief		GPS with normal use of a TinyGPS++ (TinyGPSPlus) object.
//! \brief		It requires the use of SoftwareSerial, and assumes that you have a
//! \brief		4800-baud serial GPS device hooked up on pins 4(rx) and 5(tx).
//! \date		2015-May
//! \author		minbiocabanon
//--------------------------------------------------

#include <EEPROM.h>
#include <Time.h>
#include <Timer.h>
#include <TimeAlarms.h>
#include <TinyGPS++.h>
#include <SoftwareSerial.h>
#include <Shieldfox.h>

#include "sketche_sigfoxuino.h"

//flags
boolean bFlagTimeoutgpsfix = false ;
boolean bFlagDailyFix = false ;
boolean bFlagGPSfix = false;
boolean bFlagTransmitting = false;
boolean bFlagFirstFix = true;
boolean bFlagMsgInterval = true;
unsigned int sm_state = SM_NIL;
unsigned int ledgreen = 16;                 // LED GPS connected to digital pin 16
unsigned int ledorange = 17;                // LED RF12 connected to digital pin 17
static const int GPSRXPin = 4, GPSTXPin = 5;
static const uint32_t GPSBaud = 9600;
int EventTimeOutGPSFix;
unsigned long distanceKmToMyLoc;

int addr_eeprom_msg24h = 00;				// EEPROM address where is stored nb of msg sent by 24h
int addr_eeprom_msg = 01;					// EEPROM address where is stored total nb of message sent

// Offset hours from gps time (UTC)
const int offset = 0;   // UTC time -> don't use any zone, time zone will be compute on the ground side.

unsigned char Data_ascii[25];

stTrame Data;
stTrame_byte Data_byte;
	
TinyGPSPlus gps;							// The TinyGPS++ object
Shieldfox_ shieldfox;						// The shieldfox object
SoftwareSerial GpsSerial(GPSRXPin, GPSTXPin);	// The serial connection to the GPS device
time_t prevDisplay = 0; 					// when the digital clock was displayed
Timer t;

//----------------------------------------------------------------------
//!\brief         
//!\param[in]     
//!\return        
//---------------------------------------------------------------------- 
void readGPS(void){
	GpsSerial.listen();
	//some debug message, can be commented
	printInt(gps.satellites.value(), gps.satellites.isValid(), 5);
	printInt(gps.hdop.value(), gps.hdop.isValid(), 5);
	printFloat(gps.location.lat(), gps.location.isValid(), 11, 6);
	printFloat(gps.location.lng(), gps.location.isValid(), 12, 6);
	printInt(gps.location.age(), gps.location.isValid(), 5);
	printDateTime(gps.date, gps.time);
	printFloat(gps.altitude.meters(), gps.altitude.isValid(), 7, 2);
	printFloat(gps.course.deg(), gps.course.isValid(), 7, 2);
	printFloat(gps.speed.kmph(), gps.speed.isValid(), 6, 2);
	printStr(gps.course.isValid() ? TinyGPSPlus::cardinal(gps.course.value()) : "*** ", 6);
	// end of debug 
	
	//compute distance in meter betweem GPS fix and MyLoc
	distanceKmToMyLoc =
		(unsigned long)TinyGPSPlus::distanceBetween(
			gps.location.lat(),
			gps.location.lng(),
			MY_LAT, 
			MY_LON);
	printInt(distanceKmToMyLoc, gps.location.isValid(), 9);
	Serial.println();
}

//----------------------------------------------------------------------
//!\brief         Set clock with GPS time
//!\param[in]     -
//!\return        -
//---------------------------------------------------------------------- 
void SetClockWithGPS(void){
	if( gps.location.isValid() && gps.location.age() < 500 ) {
		//GPS fix is OK, we can update the clock !
		if( bFlagFirstFix == true){
			//update time
			update_datetime();
			bFlagFirstFix = false;
			Alarm.alarmRepeat(12,00,00,DailyAlarm); // every day
			//Alarm.timerRepeat(300, DailyAlarm);  	// !!! TEST !!!
			//Alarm.timerRepeat(3600, HourAlarm);   // timer for every 1 hour 
			// Send a message for the first GPS Fix 
			bFlagDailyFix = true;			
		}
	}
}

//----------------------------------------------------------------------
//!\brief         Check if GPS position is inside area
//!\param[in]     -
//!\return        -
//---------------------------------------------------------------------- 
void CheckGeofencing(void){
	if( gps.location.isValid() && gps.hdop.value() <= HDOP_FIX_OK ) {
		// stop timeout gpsfix
		 t.stop(EventTimeOutGPSFix);
		// reset timeout fix flag 
		bFlagTimeoutgpsfix = false;
		// set GPS fix flag
		bFlagGPSfix = true;
		// if position is outside the authorised area
		if( distanceKmToMyLoc >= RADIUS_GEOFENCING && bFlagMsgInterval == true){
			Serial.println("D: -> ALARME , position is outisde authorised area !!!!!!!!!!!");			
			// set flags
			bFlagMsgInterval = false;
			// start 10 minutes interval between messages
			Alarm.timerOnce(INTERVAL_SIGFOX, TenMinInterval); 
			// switch to TRANSMIT mode for sending a message
			sm_state = SM_TRANSMIT ;
			Serial.println("D: -> transmit mode");			
		}
		else{
			// switch to STANDBY mode because everything is OK
			sm_state = SM_STANDBY ;
		}
	}
	else{
		//GPS is searching satellites
		bFlagGPSfix = false;
	}
}

//----------------------------------------------------------------------
//!\brief         Check if a daily fix occurs and then transmit a message
//!\param[in]     -
//!\return        -
//---------------------------------------------------------------------- 
void CheckDailyFix(void){
	if( bFlagDailyFix == true ){	
		if( gps.location.isValid() && gps.hdop.value() <= HDOP_FIX_OK ) {
			// switch to TRANSMIT mode for sending a message
			sm_state = SM_TRANSMIT ;
			Serial.println("D: -> Daily Fix - GPS fix ok , go to SM_TRANSMIT");	
		}
		else{
			Serial.println("D: -> Daily Fix - GPS NOK , DO nothing ???");			
		}
		// reset flag because GPS is not OK
		bFlagDailyFix = false;
	}
}

//----------------------------------------------------------------------
//!\brief         
//!\param[in]     
//!\return        
//---------------------------------------------------------------------- 
int ConvertTrame(stTrame *Data, stTrame_byte *Data_byte) {
  Data_byte->lattitude   = (long)( Data->ln_lattitude * 1000000 );
  Data_byte->longitude   = (long)( Data->ln_longitude * 1000000 );
  Data_byte->cap         = (unsigned char)( Data->f_cap / 10 );
  Data_byte->vitesse     = (unsigned char)Data->f_vitesse;
  Data_byte->temperature = (char)Data->f_temperature;
  Data_byte->tension     = (unsigned char)( Data->f_tension * 10) ;
}

//----------------------------------------------------------------------
//!\brief         
//!\param[in]     
//!\return        
//---------------------------------------------------------------------- 
void hexDump (char *desc, void *addr, int len) {
    int i;
    unsigned char *pc = (unsigned char*)addr;

    // Output description if given.
    if (desc != NULL){
		Serial.print (desc);
		Serial.println(":");
	}
    // Process every byte in the data.
    for (i = 0; i < len; i++) {
		Serial.print(" ");
		Serial.print(pc[i], HEX);
    }
	Serial.println(" ");
}
//----------------------------------------------------------------------
//!\brief         
//!\param[in]     
//!\return        
//---------------------------------------------------------------------- 
void hexascii (void *addr_buff_byte, void *addr_buff_ascii, int len) {
	unsigned char *pc = (unsigned char*)addr_buff_byte;
	unsigned char *buffTmp = (unsigned char*)addr_buff_ascii;
	
	byte j = 0;
	for(byte i=0; i <len ; i++){
		buffTmp[j] = ( pc[i] & 0xF0) >> 4;
		if (buffTmp[j] <= 0x09)
			buffTmp[j] = buffTmp[j] + 0x30;
		else	
			buffTmp[j] = buffTmp[j] + 0x41 - 0x0A;	
		j++;
		
		buffTmp[j] = pc[i] & 0x0F;
		if (buffTmp[j] <= 0x09)
			buffTmp[j] = buffTmp[j] + 0x30;
		else	
			buffTmp[j] = buffTmp[j] + 0x41 - 0x0A;
		j++;
	}
	buffTmp[j++] = '\0';
	
	// DEBUG 
	// Serial.print("buffer ascii :");
	// for (int i = 0; i < 25; i++) {
		// Serial.print(buffTmp[i]);
		// Serial.print(" ");
    // }
}

//----------------------------------------------------------------------
//!\brief         
//!\param[in]     
//!\return        
//---------------------------------------------------------------------- 
void update_datetime(void){
		Serial.print("D: -> update date/time : ");
		// set the Time to the latest GPS reading
		setTime(gps.time.hour(), gps.time.minute(), gps.time.second(), gps.date.day(), gps.date.month(), gps.date.year());
		adjustTime(offset * SECS_PER_HOUR);
		// prevDisplay = now();
		digitalClockDisplay();  
	

	// if (timeStatus()!= timeNotSet) {
		// if (now() != prevDisplay) { //update the display only if the time has changed
		  // prevDisplay = now();
		  // digitalClockDisplay();  
		// }
	// }	
}

//----------------------------------------------------------------------
//!\brief         
//!\param[in]     
//!\return        
//---------------------------------------------------------------------- 
void transmitmessage(void){
	
	GpsSerial.end();
		
	digitalWrite(ledorange, HIGH);
	Serial.println("D: in transmitmessage() function");
	
	Data.ln_lattitude = gps.location.lat();
	Data.ln_longitude = gps.location.lng();
	Data.f_cap = (int) gps.course.deg();
	Data.f_vitesse = (int) gps.speed.kmph();
	Data.f_temperature = 25.0;
	Data.f_tension = 3.30;

	ConvertTrame(&Data, &Data_byte);	
	//DEBUG
	hexDump ("Data_byte", &Data_byte, sizeof (Data_byte));
	
	// hexascii(&Data_byte, &Data_ascii, sizeof (Data_byte));
	
	// Serial.print("buffer ascii :");
	// for (int i = 0; i < 25; i++) {
		// Serial.print(Data_ascii[i]);
		// Serial.print(" ");
    // }
	// Serial.println();
	
	Serial.print("D: Sending message over Sigfox");
	//send buffer on sigfox network
	if(shieldfox.send(&Data_byte, sizeof(Data_byte)) == true){
		// if sent successfull
		// read eeprom counter values
		Serial.println("Sigfox module OK (SFM msg)");
		Serial.println("D: Reading EEPROM values");
		int valuemsg24h = EEPROM.read(addr_eeprom_msg24h);
		int valuemsg = EEPROM.read(addr_eeprom_msg);
		Serial.print("D: value : 24h = ");
		Serial.print(valuemsg24h);
		Serial.print(", total = ");
		Serial.println(valuemsg);
		// incremente counter values
		EEPROM.write(addr_eeprom_msg24h, ++valuemsg24h);
		EEPROM.write(addr_eeprom_msg, ++valuemsg);
		Serial.print("D: incremented EEPROM value : 24h = ");
		Serial.print(valuemsg24h, DEC); 
		Serial.print(", total = ");
		Serial.println(valuemsg, DEC);
	}
	else{
		Serial.println("Sigfox module return NOK (SFM msg)");
	}
		
	// go back to STANDBY mode
	sm_state = SM_STANDBY;
	// reset daily flag to not send a position again
	bFlagDailyFix = false ;
	digitalWrite(ledorange, LOW);
	
	GpsSerial.begin(GPSBaud);
}

//----------------------------------------------------------------------
//!\brief         
//!\param[in]     
//!\return        
//---------------------------------------------------------------------- 
void timeoutgpsfix(){

	// If we are in the daily fix, we force a TRANSMIT mode
	if ( bFlagDailyFix == true){
		// reset flag
		bFlagDailyFix = false ;
		// GPS running since TIMEOUT_GPS_FIX without fix, flag set !
		bFlagTimeoutgpsfix = true;
		// switch to TRANSMIT mode for sending a message
		sm_state = SM_TRANSMIT ;	
	}
	else{
		// GPS running since TIMEOUT_GPS_FIX without fix, flag set !
		bFlagTimeoutgpsfix = true;
		//go back un STANDBY mode
		sm_state = SM_STANDBY;
	}
}

//----------------------------------------------------------------------
//!\brief         
//!\param[in]     
//!\return        
//---------------------------------------------------------------------- 
void greenledtask(){

	if(bFlagGPSfix == true){
		digitalWrite(ledgreen, HIGH);
		smartDelay(50);
		digitalWrite(ledgreen, LOW);
	}
	else{
		digitalWrite(ledorange, HIGH);
		smartDelay(50);
		digitalWrite(ledorange, LOW);
	}
}

//----------------------------------------------------------------------
//!\brief         
//!\param[in]     
//!\return        
//---------------------------------------------------------------------- 
// This custom version of delay() ensures that the gps object
// is being "fed".
static void smartDelay(unsigned long ms)
{
	unsigned long start = millis();
	do{
		while (GpsSerial.available())
			gps.encode(GpsSerial.read());
	}while (millis() - start < ms);
}

//----------------------------------------------------------------------
//!\brief         
//!\param[in]     
//!\return        
//---------------------------------------------------------------------- 
// functions to be called when an alarm triggers:
void TenMinInterval(void){
	Serial.println("D: TenMinInterval expired !!!!!!!!!!!");
	//reset flag to allow sending sigfox message again
	bFlagMsgInterval = true;

}
//----------------------------------------------------------------------
//!\brief         
//!\param[in]     
//!\return        
//---------------------------------------------------------------------- 
// functions to be called when an alarm triggers:
void DailyAlarm(void){
	Serial.println("D: PROCEED TO DAILY FIX !!!!!!!!!!!");
	bFlagDailyFix = true;
	
	// erase 24h msg counter stored in eeprom
	EEPROM.write(addr_eeprom_msg24h, 00);
	//launch timeout fix GPS 
	t.after(TIMEOUT_GPS_FIX, timeoutgpsfix);
	sm_state = SM_ACTIVE;
}

//----------------------------------------------------------------------
//!\brief         
//!\param[in]     
//!\return        
//---------------------------------------------------------------------- 
// functions to be called when an alarm triggers:
void HourAlarm(void){
	Serial.println("D: PROCEED TO HOUR FIX !!!!!!!!!!!");
	bFlagDailyFix = true;
	
	// erase 24h msg counter stored in eeprom
	EEPROM.write(addr_eeprom_msg24h, 00);
	//launch timeout fix GPS 
	t.after(TIMEOUT_GPS_FIX, timeoutgpsfix);
	sm_state = SM_ACTIVE;
}


//----------------------------------------------------------------------
//!\brief       set system into the sleep state   
//!\brief       system wakes up when wtchdog is timed out 
//!\param[in]     
//!\return        
//---------------------------------------------------------------------- 
void system_sleep() {
	// Serial.println("D: sleep mode ZZzz");
	// smartDelay(500);
	// Serial.println("D: exit from sleep mode");
}

//----------------------------------------------------------------------
//!\brief         
//!\param[in]     
//!\return        
//---------------------------------------------------------------------- 
static void printFloat(float val, bool valid, int len, int prec)
{
  if (!valid)
  {
    while (len-- > 1)
      Serial.print('*');
    Serial.print(' ');
  }
  else
  {
    Serial.print(val, prec);
    int vi = abs((int)val);
    int flen = prec + (val < 0.0 ? 2 : 1); // . and -
    flen += vi >= 1000 ? 4 : vi >= 100 ? 3 : vi >= 10 ? 2 : 1;
    for (int i=flen; i<len; ++i)
      Serial.print(' ');
  }
  smartDelay(0);
}

//----------------------------------------------------------------------
//!\brief         
//!\param[in]     
//!\return        
//---------------------------------------------------------------------- 
static void printInt(unsigned long val, bool valid, int len)
{
	char sz[32] = "*****************";
	if (valid)
		sprintf(sz, "%ld", val);
	sz[len] = 0;
	for (int i=strlen(sz); i<len; ++i)
		sz[i] = ' ';
	if (len > 0) 
		sz[len-1] = ' ';
	Serial.print(sz);
	smartDelay(0);
}

//----------------------------------------------------------------------
//!\brief         
//!\param[in]     
//!\return        
//---------------------------------------------------------------------- 
static void printDateTime(TinyGPSDate &d, TinyGPSTime &t)
{
	if (!d.isValid()){
		Serial.print(F("********** "));
	}
	else{
		char sz[32];
		sprintf(sz, "%02d/%02d/%02d ", d.month(), d.day(), d.year());
		Serial.print(sz);
	}

	if (!t.isValid()){
		Serial.print(F("******** "));
	}
	else{
		char sz[32];
		sprintf(sz, "%02d:%02d:%02d ", t.hour(), t.minute(), t.second());
		Serial.print(sz);
	}

	printInt(d.age(), d.isValid(), 5);
	smartDelay(0);
}

//----------------------------------------------------------------------
//!\brief         
//!\param[in]     
//!\return        
//---------------------------------------------------------------------- 
static void printStr(const char *str, int len)
{
	int slen = strlen(str);
	for (int i=0; i<len; ++i)
		Serial.print(i<slen ? str[i] : ' ');
	smartDelay(0);
}

//----------------------------------------------------------------------
//!\brief         
//!\param[in]     
//!\return        
//---------------------------------------------------------------------- 
void digitalClockDisplay(){
	// digital clock display of the time
	Serial.print(hour());
	printDigits(minute());
	printDigits(second());
	Serial.print(" ");
	Serial.print(day());
	Serial.print(" ");
	Serial.print(month());
	Serial.print(" ");
	Serial.print(year()); 
	Serial.println(); 
}

//----------------------------------------------------------------------
//!\brief         
//!\param[in]     
//!\return        
//---------------------------------------------------------------------- 
void printDigits(int digits) {
	// utility function for digital clock display: prints preceding colon and leading 0
	Serial.print(":");
	if(digits < 10)
		Serial.print('0');
	Serial.print(digits);
}

//----------------------------------------------------------------------
//!\brief         
//!\param[in]     
//!\return        
//---------------------------------------------------------------------- 
void statemachine(void){
	// do action follow state machine status
	switch(sm_state) {
		case SM_NIL:
			// Do nothing
			break;
		case SM_STANDBY:
			system_sleep();
			// at startup, launch timeout fix GPS 
			t.after(TIMEOUT_GPS_FIX, timeoutgpsfix);
			//switch to ACTIVE mode
			sm_state = SM_ACTIVE;
			break;
		case SM_ACTIVE:
			// get GPS position
			readGPS();
			// compare GPS position with autorized area
			CheckGeofencing();
			// check if a daily fix and message has to be sent
			CheckDailyFix();
			// set clock with GPS time
			SetClockWithGPS();
			break;
		case SM_TRANSMIT:
			// send a message
			transmitmessage();
			break;			
	}
}

//----------------------------------------------------------------------
//!\brief         
//!\param[in]     
//!\return        
//---------------------------------------------------------------------- 
void setup(){
	// Open serial communications and wait for port to open:
	Serial.begin(115200);
	
	setTime(18,20,0,10,8,15); 					// set time to Saturday 8:29:00am Jan 1 2011
	// Alarm.alarmRepeat(21,37,0,DailyAlarm);	// 5:45pm every day

	GpsSerial.begin(GPSBaud);
	// Initialize sigfox modem
	shieldfox.begin();
	pinMode(ledgreen, OUTPUT);      // sets the digital pin as output
	pinMode(ledorange, OUTPUT);      // sets the digital pin as output
	digitalWrite(ledgreen, HIGH);
	digitalWrite(ledorange, LOW);
	
	Serial.println(F("Sats HDOP Latitude   Longitude   Fix  Date       Time     Date Alt    Course Speed Card   Distance "));
	Serial.println(F("          (deg)      (deg)       Age                      Age  (m)    --- from GPS ----   to Myloc "));
  
	// at startup, launch timeout fix GPS 
	EventTimeOutGPSFix =  t.after(TIMEOUT_GPS_FIX, timeoutgpsfix);
	t.every(PERIOD_CHECK_FIX, greenledtask);
	
	sm_state = SM_STANDBY;
  	Serial.println("Setup done.");	
}

//----------------------------------------------------------------------
//!\brief         
//!\param[in]     
//!\return        
//---------------------------------------------------------------------- 
void loop(){
	statemachine();	
	//for shedulers
	t.update();
	Alarm.delay(0);
	smartDelay(PERIOD_CHECK_FIX);
}

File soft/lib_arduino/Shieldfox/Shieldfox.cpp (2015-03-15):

// shieldfox library - inspired by http://akeru.cc
//
// copyleft 2014
// this code is public domain, enjoy!

#include <Arduino.h>
#include "Shieldfox.h"

Shieldfox_ Shieldfox;

Shieldfox_::Shieldfox_() :
    _serial(3, 2) {
     //Since _lastSend is unsigned, this is infinity
    _lastSend = -1;
}

Shieldfox_::~Shieldfox_() {	
}

void Shieldfox_::begin() {
    _serial.begin(9600);


    //Remove un-ended commands from TST's buffer
    _serial.write((uint8_t)'\0');
    _serial.write((uint8_t)';');

    //Wait for the "KO;"
    while(_serial.available() < 3);

    _serial.read(); //'K'
    _serial.read(); //'O'
    _serial.read(); //';'
}


bool Shieldfox_::isReady() {

	// IMPORTANT WARNING. PLEASE READ BEFORE MODIFYING THE CODE
	//
	// The Sigfox network operates on public frequencies. To comply with
	// radio regulation, it can send radio data a maximum of 1% of the time
	// to leave room to other devices using the same frequencies.
	//
	// Sending a message takes about 6 seconds (it's sent 3 times for
	// redundancy purposes), meaning the interval between messages should
	// be 10 minutes.
	//
	// Also make sure your send rate complies with the restrictions set
	// by the particular subscription contract you have with your Sigfox
	// network operator.
	//
	// FAILING TO COMPLY WITH THESE CONSTRAINTS MAY CAUSE YOUR MODEM
	// TO BE BLOCKED BY YOUR SIFGOX NETWORK OPERATOR.
	//
	// You've been warned!

    unsigned long currentTime = millis();
    if(currentTime >= _lastSend && (currentTime - _lastSend) <= 600000) {
        return false;
    }
	
    // Time is ok, ask the modem's status
    _serial.write((uint8_t)'\0');
    _serial.write((uint8_t)'S');
    _serial.write((uint8_t)'F');
    _serial.write((uint8_t)'P');
    _serial.write((uint8_t)';');
	
    return _nextReturn() == OK;
}

bool Shieldfox_::send(const void* data, uint8_t len) {
	uint8_t* bytes = (uint8_t*)data;
	
	_serial.listen();

    if(!isReady()) {
        return false;
    }

	
    // See comment in isReady()
    _lastSend = millis();

    _serial.write((uint8_t)'\0');
    _serial.write((uint8_t)'S');
    _serial.write((uint8_t)'F');
    _serial.write((uint8_t)'M');
    _serial.write(len);
    for(uint8_t i = 0; i < len; ++i) {
        _serial.write(bytes[i]);
    }
    _serial.write(';');
	
    uint8_t ok = _nextReturn();
    if(ok == OK) {
        _nextReturn(); //SENT
        return true;
    }
    return false;
}

uint8_t Shieldfox_::getRev() {
    _serial.write((uint8_t)'\0');
    _serial.write((uint8_t)'S');
    _serial.write((uint8_t)'F');
    _serial.write((uint8_t)'v');
    _serial.write((uint8_t)';');

    while(_serial.available()<3);

    if(_serial.peek() == 'K') {
        _serial.read(); //'K'
        _serial.read(); //'O'
        _serial.read(); //';'
        return 0;
    } else {
        while(_serial.available()<5);
        uint8_t rev = 10 * (_serial.read() - '0') + (_serial.read() - '0');

        _serial.read(); //'O'
        _serial.read(); //'K'
        _serial.read(); //';'

        return rev;
    }
}

unsigned long Shieldfox_::getID() {
    _serial.write((uint8_t)'\0');
    _serial.write((uint8_t)'S');
    _serial.write((uint8_t)'F');
    _serial.write((uint8_t)'I');
    _serial.write((uint8_t)'D');
    _serial.write((uint8_t)';');

    //Response is [byte1, byte2, ..., byteN, 'O', 'K']
    uint8_t response[8] = {0};
    uint8_t i = 0;
    while(!_serial.available());
    while(_serial.peek() != ';') {
        response[i] = _serial.read();
        while(!_serial.available());
        ++i;
    }
    _serial.read(); //';'

    unsigned long id = 0;

    for(uint8_t j = 0; j < i-2; ++j) {
        id += response[j] << ((i-3-j) * 8);
    }

    return id;
}
//Power value:
//0 -25 -30 dBm
//1 0dBm
//2 14dBm
//3 16dBm
//4 18dBm
//5 Max (18-19dBm)
bool Shieldfox_::setPower(uint8_t power) {
    power = power % 6; //It's 0-5
    _serial.write((uint8_t)'\0');
    _serial.write((uint8_t)'S');
    _serial.write((uint8_t)'F');
    _serial.write((uint8_t)'G');
    _serial.write(power);
    _serial.write((uint8_t)';');

    return _nextReturn() == OK;
}

uint8_t Shieldfox_::_nextReturn() {
    while(!_serial.available());
	char fstChar = _serial.read();
    while(_serial.read() != ';');
    return fstChar;
}

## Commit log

2015-03-15 first commit with all files
    [BOM-CI14-001_Sigfoxuino.ods, BOM_sigfoxuino.csv, Config_RF12.ods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]
2015-09-27 - add sketche_sigfoxuino.h file with prototype and enumerate - add daily fix - fix some bugs
    [sketche_sigfoxuino.ino]
